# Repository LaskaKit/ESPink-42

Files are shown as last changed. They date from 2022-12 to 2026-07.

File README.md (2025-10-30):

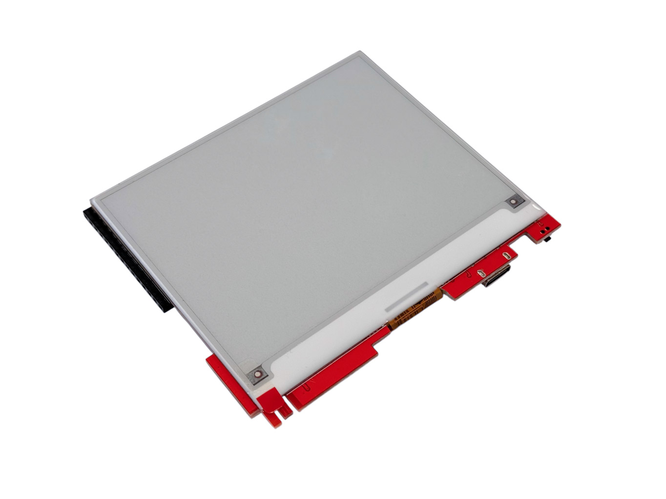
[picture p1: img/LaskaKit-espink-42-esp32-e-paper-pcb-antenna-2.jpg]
ESPink 4.2" top

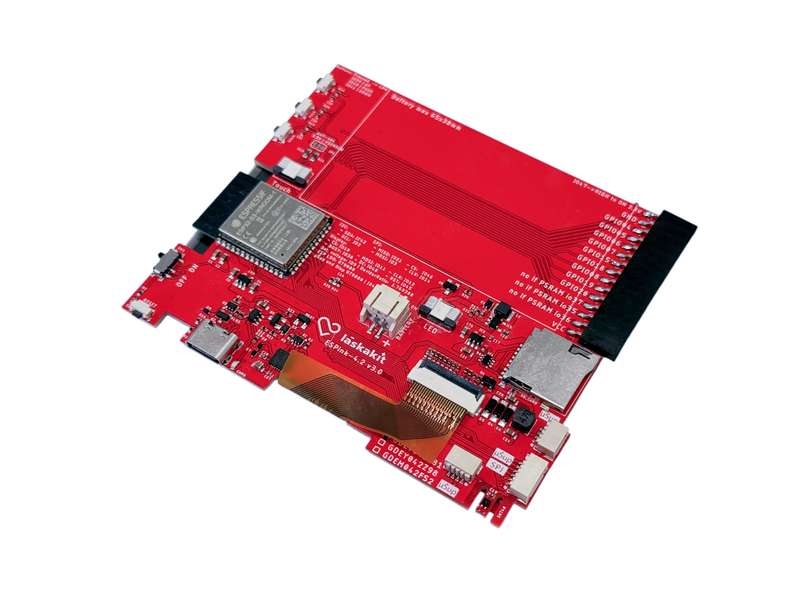
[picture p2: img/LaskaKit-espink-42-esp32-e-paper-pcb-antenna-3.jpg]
ESPink 4.2" bottom


# LaskaKit ESPink-4.2" — universal and ultra-low-power ESP32 board for 4.2" ePaper displays

[ePaper displays](https://www.laskakit.cz/e-ink/) are becoming incredibly popular — and for good reason.  
Their extremely low power consumption and wide viewing angle make them ideal for many battery-powered projects.  
But what’s the best way to drive such a display? That’s why we designed **ESPink** — a board with large memory, low power consumption, easy I²C sensor connection, and a huge maker community around ESP32.

---

## Main Features

The board naturally includes a connector for ePaper displays (sometimes referred to as *E-Ink*).  
While ePaper is very energy-efficient, it still draws a few microamps even when idle.  
To minimize this current, display power is controlled by a voltage regulator switched through **GPIO47**.  
The display power turns on when GPIO47 is set to HIGH.

The board can be powered by a **Li-Po battery**, which is charged via the **USB-C** connector.  
Battery voltage can be measured thanks to an integrated voltage divider connected to **GPIO9**.

Connecting sensors has never been easier or safer.  
No more broken sensors due to reversed polarity — with our **μŠup connector** (with a locking mechanism), you can plug sensors in quickly and securely.  
Compatible sensors include:  
- [LaskaKit SHT40 temperature and humidity sensor](https://www.laskakit.cz/laskakit-sht40-senzor-teploty-a-vlhkosti-vzduchu/)  
- [LaskaKit SCD41 CO₂, temperature, and humidity sensor](https://www.laskakit.cz/laskakit-scd41-senzor-co2--teploty-a-vlhkosti-vzduchu/)

The board also provides plenty of **GPIO pins** for your own extensions or modules.  
Power consumption in deep-sleep mode is extremely low — perfect for long-term battery projects.

---

## Important Notice

Recently shipped boards are equipped with **GoodDisplay displays**.  
The original **Waveshare** versions are no longer in production.  
At this time, there may be **incompatibility with ESPHome**, since support for new GoodDisplay panels is not yet fully implemented.  
If you plan to use ESPHome, please verify compatibility before purchase.

---

## Versions and Specifications

### ESPink-4.2" v3.0

| Display Type | Model | Colors | Refresh |
|---|---|---|---|
| Black & White | GDEQ042T81 | BW Grayscale | partial refresh |
| Black & White (touch + backlight) | GDEY042T81-FT02 | BW Touch | partial refresh |
| Red-Black-White | GDEY042Z98 | RBW | full refresh ~22 s |
| Yellow-Red-Black-White | GDEM042F52 | YRBW | full refresh ~20 s |

**ESP32 module:** ESP32-S3-N16R8 (16 MB Flash, 8 MB PSRAM)  
**Input voltage:** 3.7 – 5.5 V  
**Power consumption (deep-sleep):**
- Without touch: 16 µA  
- With touch: 4.5 mA for first 30 s, then 1.55 mA  
**Digital I/O pins:** 32  
**Analog inputs:** 16  
**Recommended battery:** GeB Li-Po 503759 – 1200 mAh  

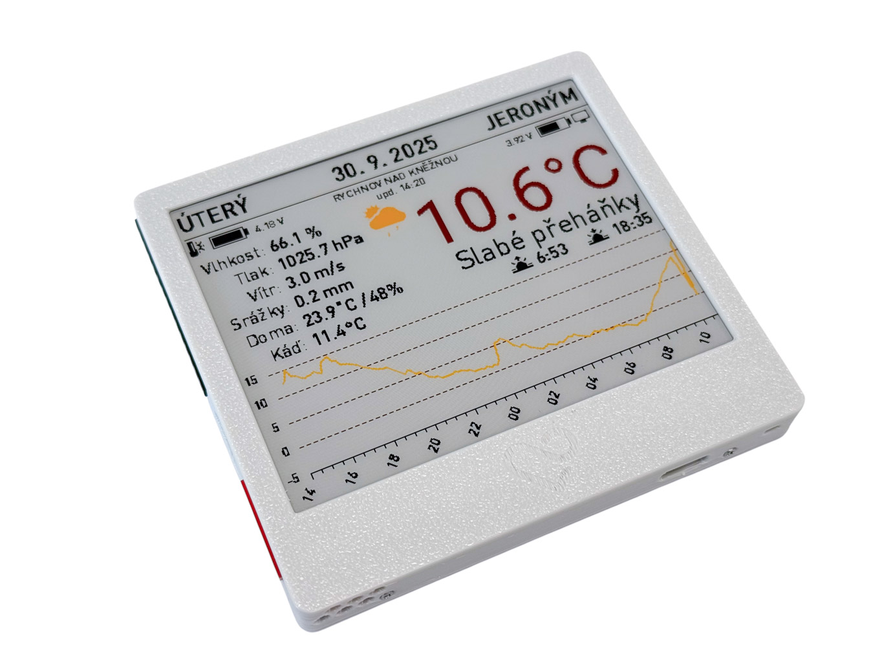
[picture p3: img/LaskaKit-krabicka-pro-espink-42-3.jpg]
ESPink 4.2" case


---

## Pinout (GxEPD2 standard)

| Function | Pin |
|---|-----|
| MOSI / SDI | 23 |
| CLK / SCK | 18 |
| SS / CS | 5 |
| DC | 17 |
| RST | 16 |
| BUSY | 4 |
| ePaper Power (HIGH = ON) | 47 |

---

## μŠup Connector Pinout

### SPI_uSUP
| Signal | Pin |
|---|-----|
| CS | 46 |
| MOSI | 3 |
| SCK | 14 |
| MISO | 21 |

### I2C_uSUP
| Signal | Pin |
|---|-----|
| SDA | 42 |
| SCL | 2 |

### SD Card
| Signal | Pin |
|---|-----|
| CS | 17 |
| MOSI | 11 |
| SCK | 12 |
| MISO | 13 |
| SD Insert | 16 |

### Buttons
| Function | Pins |
|---|---|
| Buttons | 39, 40, 41 |

---

📦 **Buy ESPink-4.2" in our e-shop:**  
➡️ [https://www.laskakit.cz/laskakit-espink-42-esp32-e-paper-pcb-antenna/](https://www.laskakit.cz/laskakit-espink-42-esp32-e-paper-pcb-antenna/)

💾 **Example codes and demos:**  
➡️ [https://github.com/LaskaKit/ESPink-42/tree/main/SW](https://github.com/LaskaKit/ESPink-42/tree/main/SW)

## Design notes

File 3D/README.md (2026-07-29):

#### Enclosure file moved to : https://github.com/LaskaKit/Live/tree/main/4.2

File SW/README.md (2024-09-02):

# How to make display work - Windows

1. Download [CH343SER.EXE](http://www.wch-ic.com/search?t=all&q=CH9102) and install it.

2. Connect display to your PC and turn it on with button on the side of the device (**single press to turn on, long press to turn off**).

3. Open Device Manager (Start → Control Panel → Hardware and Sound → Device Manager) and find COM port number.

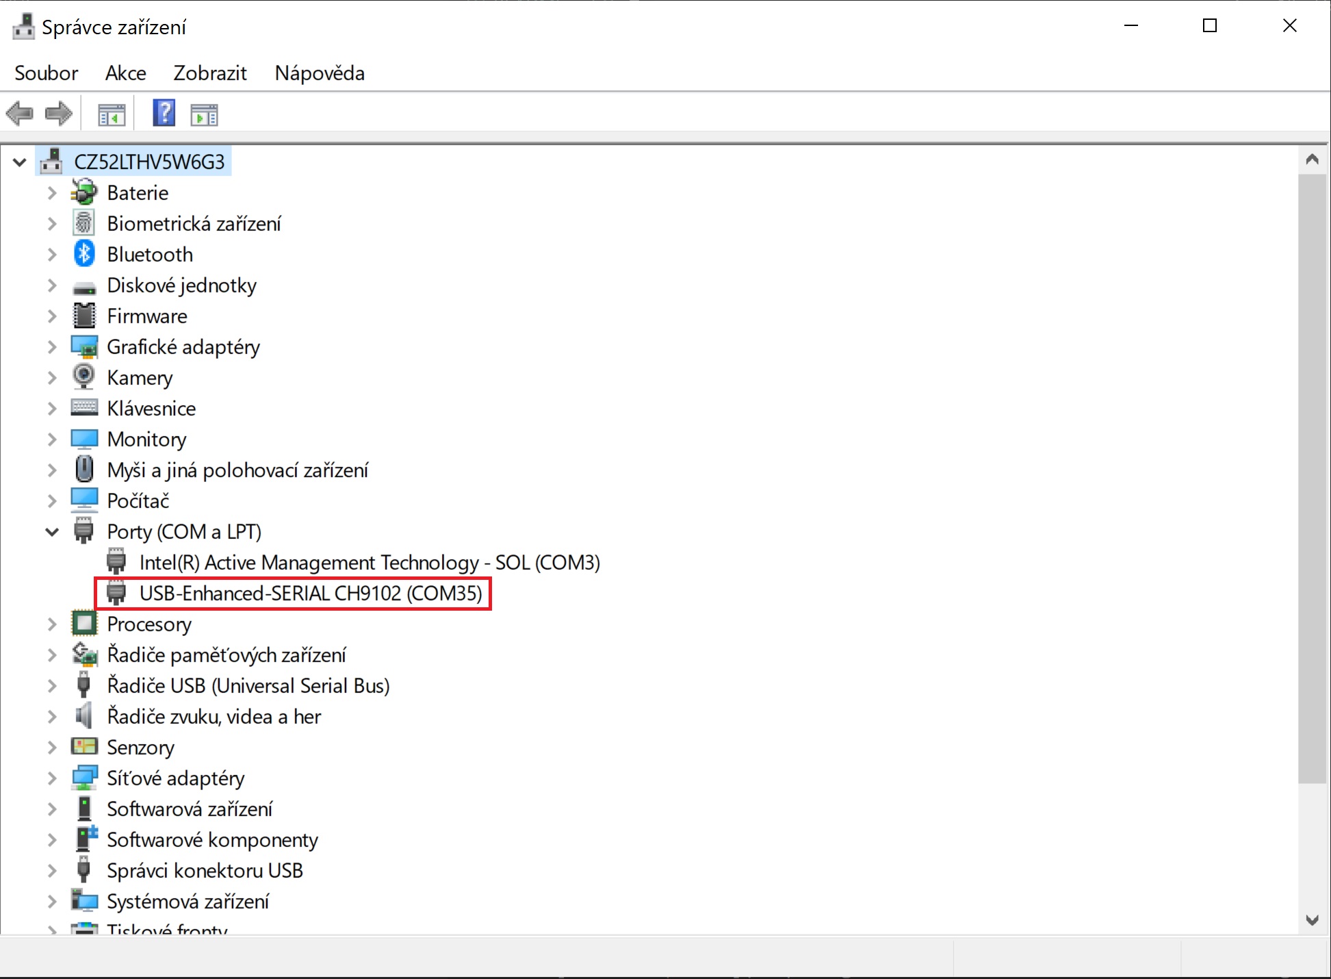
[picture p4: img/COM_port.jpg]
COM_port
    

## Arduino IDE
1. Download Github repository and look for project you want to try in [SW](../SW) folder.
2. Open example with Arduino IDE and set appropriate COM port and board type.
   
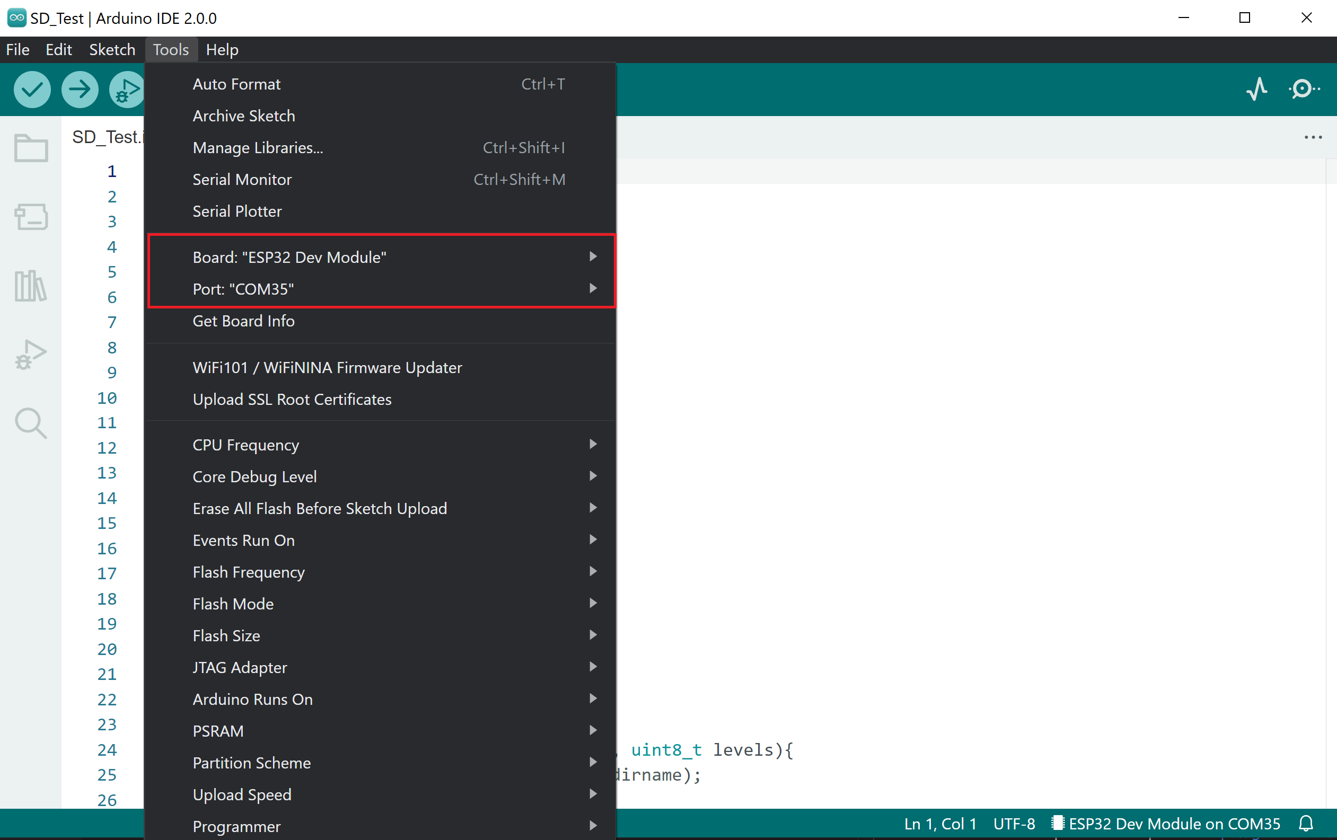
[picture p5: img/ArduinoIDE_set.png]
ArduinoIDE_set
    

3. Download necessary libraries.
4. Upload the code.
## Platform IO
1. Download Github repository and look for project you want to try in [SW](https://github.com/LaskaKit/ESPD-35/tree/main/SW) folder.
2. Open example with Platform IO. COM port should be set automaticaly.
3. Libraries will be downloaded automatically, because of lib_deps in platformio.ini.
4. Upload the code.

# How to make display work - Mac

1. Download [CH341SER_MAC.ZIP](https://www.wch-ic.com/search?t=all&q=CH9102) and unzip it
2. Run **CH34xVCPDriver.pkg** and follow the install instruction, reboot the Mac
3. Connect display to your Mac and turn it on with button on the side of the device

## Arduino IDE
1. Download Github repository and look for the project you want to try in [SW](../SW) folder.
2. Open example with Arduino IDE and set the appropriate serial port (/dev/cu.wuchsbserial) and board type.
   
ArduinoIDE_set
   
4. Download necessary libraries: [GxEPD2](https://github.com/ZinggJM/GxEPD2)
5. Upload the code.

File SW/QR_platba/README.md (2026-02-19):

# QR Platba na [ESPink4.2](https://www.laskakit.cz/laskakit-espink-42-esp32-e-paper-pcb-antenna/?variantId=13538) (ESP32 + e‑paper)

Projekt vytváří platební QR kód ve formátu Short Payment Descriptor (QR Platba, SPD 1.0) přímo na desce **[LaskaKit ESPink4.2](https://www.laskakit.cz/laskakit-espink-42-esp32-e-paper-pcb-antenna/?variantId=13538)** s ESP32 a 4,2" e‑paper displejem. Uživatel vyplní platební údaje přes webový formulář a výsledný QR kód se zobrazí na displeji, odkud jej zákazník naskenuje v mobilním bankovnictví.

Celý článek na našem blogu https://blog.laskakit.cz/epaper-jako-zobrazeni-qr-platby-pripravili-jsme-univerzalni-kod-zdarma-staci-pouzit/

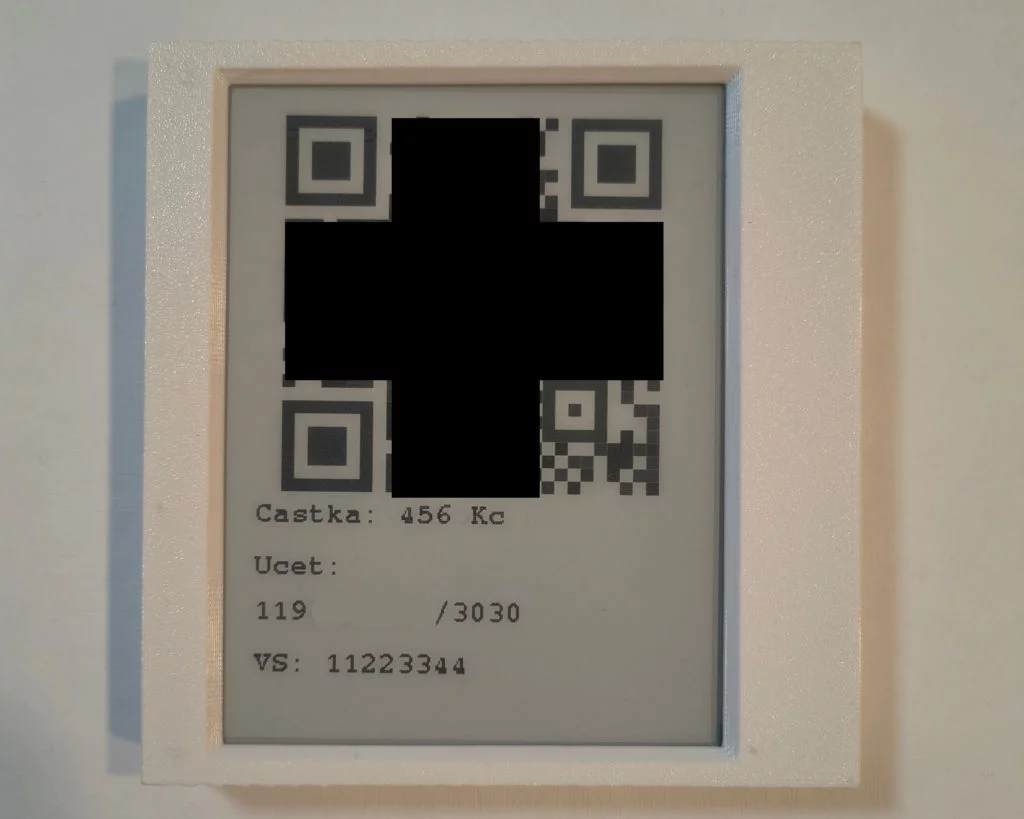
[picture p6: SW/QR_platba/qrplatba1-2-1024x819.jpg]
Obrazek


## Funkce

- Připojení k uložené Wi‑Fi nebo vytvoření vlastní Wi‑Fi AP **„Laskakit‑Platba_QR“** (heslo **„esp32qrpay“**) s jednoduchým webovým rozhraním.
- Webový formulář pro zadání částky (Kč), IBAN účtu, variabilního symbolu a data splatnosti a následné vygenerování QR platby.
- Generování platebního řetězce ve formátu SPD 1.0 a jeho zobrazení jako QR kódu na 4,2" e‑paper displeji.
- Uložení českého IBAN a Wi‑Fi přihlašovacích údajů do EEPROM a jejich opakované použití.
- Převod českého IBAN na domácí formát účtu (předčíslí‑číslo/kód banky) pro čitelný výpis na displeji.
- Administrační stránka `/admin` pro nastavení Wi‑Fi (SSID + heslo) a restart zařízení po uložení.

## Použitý hardware

Projekt je navržen pro:

- **LaskaKit ESPink4.2** – ESP32 modul s integrovaným 4,2" e‑paper displejem.
- ESP32 (WROOM) s Wi‑Fi.
- 4,2" e‑paper připojený přes SPI:
  - `PIN_SS` = 5  
  - `PIN_DC` = 17  
  - `PIN_RST` = 16  
  - `PIN_BUSY` = 4
- Řízení napájení e‑paper displeje na pinu `DISPLAY_POWER_PIN` (GPIO2).

Ostatní ESP32 piny jsou dle standardního zapojení desky ESPink4.2.

## Závislosti (knihovny)

Projekt je určen pro **Arduino IDE** (nebo kompatibilní build systém) s podporou ESP32.

Povinné knihovny:

- **WiFi.h** – Wi‑Fi připojení ESP32.
- **ESPAsyncWebServer** – asynchronní webový server (HTTP GET/POST, formuláře).
- **EEPROM.h** – ukládání IBAN a Wi‑Fi údajů.
- **GxEPD2_BW** – ovladač pro 4,2" e‑paper displej (černobílý režim).
- **qrcode_gen.h** (Ricmoo QRCode) – generování QR kódu z textového řetězce.
- **FreeMonoBold9pt7b** – font pro zobrazení textu na displeji.

Před kompilací ověř, že jsou knihovny nainstalované přes Library Manager nebo přidány jako Git submoduly.

## Kompilace

V Arduino IDE:

1. Nainstaluj podporu ESP32 (Boards Manager).
2. Otevři projektový `.ino` nebo `.cpp` soubor.
3. V **Tools → Board** vyber **ESP32 Dev Module**.
4. Nastav správný port a klikni na **Upload**.

## Jak to funguje

1. ESP32 po startu načte z EEPROM uložené Wi‑Fi přihlašovací údaje.
2. Pokusí se připojit k Wi‑Fi (režim STA) po dobu cca 20 s.
3. Pokud se nepřipojí, vytvoří vlastní AP **„Laskakit‑Platba_QR“** s heslem **„esp32qrpay“**.
4. Na e‑paper displeji zobrazí stav Wi‑Fi (připojeno/AP režim), SSID a IP adresu.
5. Na kořenové URL `/` běží stránka s formulářem:
   - Částka v Kč.
   - IBAN (český, formát CZ…).
   - Variabilní symbol (volitelné).
   - Datum splatnosti (volitelné).
6. Po odeslání na `/qr` proběhne:
   - Očištění IBAN od mezer a nealfanumerických znaků.
   - Kontrola, že IBAN začíná `CZ` a má délku 24 znaků.
   - Kontrola částky > 0.
   - Validace VS (max. 10 číslic).
   - Uložení IBAN do EEPROM (pokud se změnil).
   - Vytvoření SPD řetězce a vygenerování QR kódu.
   - Vykreslení QR kódu a textových údajů (částka, účet, VS) na e‑paper displej.
7. Admin stránka `/admin` umožní změnu Wi‑Fi SSID/hesla a restart zařízení.

## End‑pointy

- `GET /` – hlavní stránka pro zadání platebních údajů a vytvoření QR kódu.
- `GET /qr` – zpracování formuláře, validace vstupů, generování QR platby a vykreslení na e‑paper.
- `GET /admin` – formulář pro nastavení Wi‑Fi (SSID a heslo).
- `POST /wifi_save` – uložení Wi‑Fi údajů do EEPROM a restart ESP32.

## Bezpečnost a omezení

- Ukládání údajů do EEPROM není šifrované, projekt je tedy vhodný pro jednoduché pokladní/klubové použití, ne pro kritické scénáře.
- Validace je primárně uzpůsobena českému IBAN (`CZ` + 24 znaků).
- Okamžité platby jsou indikované parametrem `PT:IP` pouze na úrovni SPD řetězce – skutečné provedení závisí na bance.

## Možné vylepšení

- Přidání zprávy pro příjemce a dalších volitelných SPD parametrů.
- Volitelné předvyplnění částky a VS (např. přes query parametry v URL).
- Podpora více účtů nebo profilů.
- Jednoduchá ochrana admin rozhraní (heslo, PIN).

## Hardware

Celý článek na našem blogu https://blog.laskakit.cz/epaper-jako-zobrazeni-qr-platby-pripravili-jsme-univerzalni-kod-zdarma-staci-pouzit/

ESPink-42 můžete zakoupit na https://www.laskakit.cz/laskakit-espink-42-esp32-e-paper-pcb-antenna/?variantId=13538

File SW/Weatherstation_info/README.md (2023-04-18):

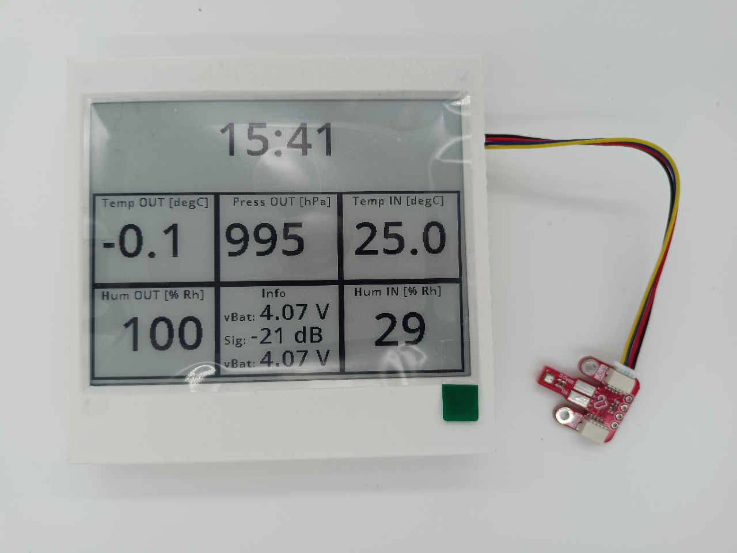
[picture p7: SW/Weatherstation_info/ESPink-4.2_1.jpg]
</br>
</br>
Example code shows values from weatherstation from TMEP.cz (temperature, humidity, pressure, battery voltage) 
and BME280 (temperature/humidity), battery voltage on eInk/ePaper display</br>
</br>
Compile as ESP32 dev module</br>
ESPink - ESP32 board for ePaper: https://www.laskakit.cz/laskakit-espink-esp32-e-paper-pcb-antenna/</br>
BME280 (https://www.laskakit.cz/arduino-senzor-tlaku--teploty-a-vlhkosti-bme280/) is connected through uSup connector </br>
</br>
ESPink pinout:</br>
MOSI/SDI 23</br>
CLK/SCK 18</br>
SS 5 //CS</br>
DC 17 </br>
RST 16  </br>
BUSY 4 </br>
ePaperPowerPin  2</br>
</br>
I2C pinout:</br>
SDA 21</br>
SCL 22</br>
</br>
Battery input:</br>
vBatPin 34</br>
</br>
Need to change based on your settings:</br>
WiFi (SSID and Password)</br>
TMEP server (jsonurl)</br>
</br>
Libraries:</br>
Analog read with calibration data: https://github.com/madhephaestus/ESP32AnalogRead/ </br>
EPD library: https://github.com/ZinggJM/GxEPD2</br>
ArduinoJson: https://arduinojson.org/</br>
Font: https://oleddisplay.squix.ch/ </br>
BME280: https://github.com/adafruit/Adafruit_BME280_Library</br>
https://github.com/adafruit/Adafruit_Sensor</br>
</br>
made by laskakit (c) 2023</br>
</br>
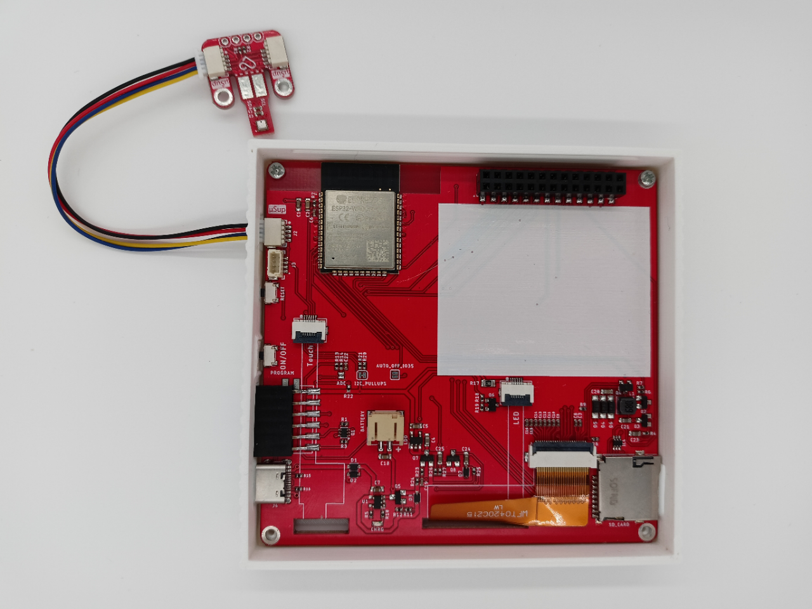
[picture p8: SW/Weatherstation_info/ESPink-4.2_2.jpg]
</br>

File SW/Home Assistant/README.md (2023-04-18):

# How to make display work

1. Add text from configuration.yaml to your configuration.yaml in Home Assistant (you do not have to change anything for testing, otherwise edit it to your needs).
   
2. Place fonts folder into esphome/config.

3. Add display to esphome and Home Assistant.
   
4. Copy text from espink.yaml to your device config yaml and edit necessary parameters. **Name of the device has to match your added device name.**

5. Upload code to your device. From now on, you are able to upload code wirelessly, just locally, because device is most of the time in sleep mode.

# What does it do?
It prints data from [TMEP](https://tmep.cz/) on the display after getting them from Home Assistant and goes to sleep.

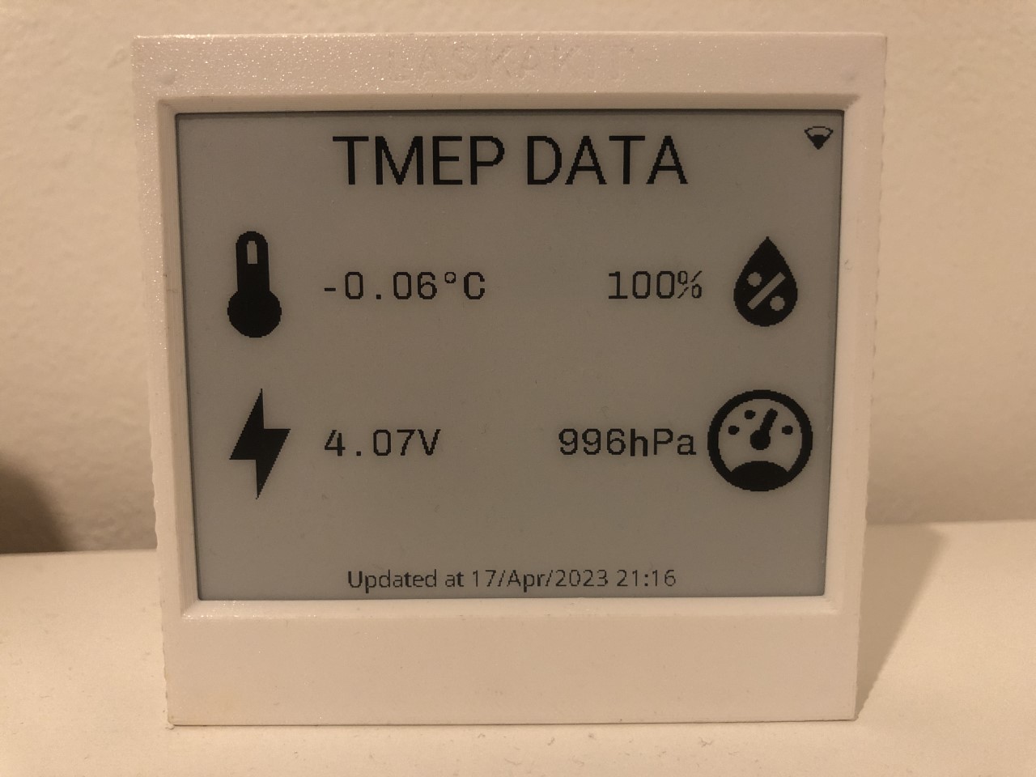
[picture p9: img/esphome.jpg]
esphome


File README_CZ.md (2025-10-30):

ESPink 4.2" top
ESPink 4.2" bottom

# LaskaKit ESPink-4.2" — univerzální a velmi úsporná deska s ESP32 pro 4.2" ePaper

[ePaper displeje](https://www.laskakit.cz/e-ink/) nabírají neuvěřitelné popularity a není divu.  
Především velmi nízký odběr a široký pozorovací úhel dělá ePaper tak populárním.  
Ale čím tento displej řídit? Proto jsme navrhli **ESPink** — desku s velkou pamětí, nízkým odběrem, snadným připojením I2C čidel a velkou komunitou bastlířů okolo ESP32.

---

## Hlavní vlastnosti

Na desce samozřejmě najdete konektor pro ePaper displeje (někdy označovaný jako *E-Ink*).  
Displej sám o sobě je velmi úsporný, ale i mimo fázi přepisu odebírá několik mikroampér.  
Abychom tento odběr minimalizovali, je napájení displeje řízené stabilizátorem spínaným přes **GPIO47**.  
Napájení ePaperu se tedy zapne, když je GPIO47 nastaven do HIGH.

Deska může být napájena z **LiPol akumulátoru**, který se nabíjí přes **USB-C** konektor.  
Napětí akumulátoru lze měřit díky integrovanému děliči připojenému na **GPIO9**.

Připojení čidel nebylo nikdy snadnější ani bezpečnější.  
Žádná nefunkční čidla kvůli přepólování — díky našemu **μŠup konektoru**, který obsahuje zámek, čidlo jednoduše a bezpečně připojíte.  
Mezi taková čidla patří například:  
- [LaskaKit SHT40 senzor teploty a vlhkosti vzduchu](https://www.laskakit.cz/laskakit-sht40-senzor-teploty-a-vlhkosti-vzduchu/)  
- [LaskaKit SCD41 senzor CO₂, teploty a vlhkosti vzduchu](https://www.laskakit.cz/laskakit-scd41-senzor-co2--teploty-a-vlhkosti-vzduchu/)

Na desce je také dostatek **GPIO pinů** pro rozšiřující moduly nebo vlastní projekty.  
Odběr v hlubokém spánku (deep-sleep) je velmi nízký — ideální pro bateriové projekty.

---

## Důležité upozornění

Nově prodávané desky využívají **displeje od výrobce GoodDisplay**.  
Původní displeje od **Waveshare** se již nevyrábějí.  
V současné době může být **nekompatibilita s ESPHome**, protože zatím není implementována podpora pro nové displeje GoodDisplay.  
Pokud používáte ESPHome, doporučujeme tuto informaci ověřit před nákupem.

---

## Verze a parametry

### ESPink-4.2" v3.0

| Typ displeje | Model | Barvy | Obnova |
|---|---|---|---|
| Černo-Bílý | GDEQ042T81 | BW Grayscale | částečný refresh |
| Černo-Bílý (dotyk + podsvit) | GDEY042T81-FT02 | BW Touch | částečný refresh |
| Červeno-Černo-Bílý | GDEY042Z98 | RBW | full refresh ~22 s |
| Žluto-Červeno-Černo-Bílý | GDEM042F52 | YRBW | full refresh ~20 s |

**ESP32 modul:** ESP32-S3-N16R8 (16 MB Flash, 8 MB PSRAM)  
**Napájení:** 3.7 – 5.5 V  
**Odběr (deep-sleep):**
- Bez dotyku: 16 µA  
- S dotykem: 4.5 mA prvních 30 s, poté 1.55 mA  
**Digitální I/O piny:** 32  
**Analogové vstupy:** 16  
**Vhodná baterie:** GeB LiPol 503759 – 1200 mAh  

ESPink 4.2" bottom

---

## Pinout (GxEPD2 standard)

| Funkce | Pin |
|---|-----|
| MOSI / SDI | 23 |
| CLK / SCK | 18 |
| SS / CS | 5 |
| DC | 17 |
| RST | 16 |
| BUSY | 4 |
| Napájení ePaperu (HIGH = ON) | 47 |

---

## Pinout konektorů μŠup

### SPI_uSUP
| Signál | Pin |
|---|-----|
| CS | 46 |
| MOSI | 3 |
| SCK | 14 |
| MISO | 21 |

### I2C_uSUP
| Signál | Pin |
|---|-----|
| SDA | 42 |
| SCL | 2 |

### SD karta
| Signál | Pin |
|---|-----|
| CS | 17 |
| MOSI | 11 |
| SCK | 12 |
| MISO | 13 |
| SD Insert | 16 |

### Tlačítka
| Funkce | Piny |
|---|---|
| Buttons | 39, 40, 41 |

---

📦 **ESPink-4.2" na e-shopu:**  
➡️ [https://www.laskakit.cz/laskakit-espink-42-esp32-e-paper-pcb-antenna/](https://www.laskakit.cz/laskakit-espink-42-esp32-e-paper-pcb-antenna/)

💾 **Vzorové kódy a ukázky:**  
➡️ [https://github.com/LaskaKit/ESPink-42/tree/main/SW](https://github.com/LaskaKit/ESPink-42/tree/main/SW)

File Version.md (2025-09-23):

### Version 3.1
- More place for flex cable
- Added one more capacitor 47uF for ESP
#### Version 3.0
- Whole new board on ESP32-S3
- pull down added to backlight pin
#### Version 3.0
- Whole new board on ESP32-S3
#### Version 2.3
- ESPD power delivery changed | Napájení ESPD změněno
- Battery voltage mesurement changed, used MAX17048 instead od ADC (First 5 minutes deep sleep current is 34 µA (before MAX17048 go to hibernate), after 5 min 14 µA) | Měření napětí baterie se změnilo, místo ADC se používá MAX17048 (prvních 5 minut deep sleep proud je 34 µA (než MAX17048 přejde do režimu spánku), po 5 minutách 14 µA)
- Resistor R9 changed to 0.47 Ohm | Rezistor R9 změněn na 0,47 Ohm
- µSup SPI connector added | Přidán konektor µSup SPI
#### Version 2.2
- Added switched stabilizer for µShup on pin 02 | Pridán spinaný stabilizator pro µŠup na pinu 02
- Changing the scheme connection for the touch panel on the new display | Změna zapojení konektoru pro touch panel na nové displeje
- Changing the scheme connection for the backlight on the new display | Změna zapojení konektoru pro podsvícení na nové displeje
- Added a 3.3V-21V converter for powering the backlight |Přidán měnič 3,3V-21V pro napájení podsvícení
- Changing the way to turn on the backlight |Změna způsobu zapínání podsvícení
#### Version 2.1
- Switch to classic switch. |změna vypinani na klasický vypinač
#### Version 2.0
- Add USB - TTL adapter | Přidan adaptér USB - TTL
- Replaced microSD card holder | Vyměněn držák microSD karty
#### Version 1.2
- Initial | Počáteční

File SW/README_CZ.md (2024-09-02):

# Jak pracovat s displejem

1. Stáhnout [CH343SER.EXE](http://www.wch-ic.com/search?t=all&q=CH9102) a nainstalovat. Návod i na našem [blogu](https://blog.laskakit.cz/instalace-ovladace-prevodniku-usb-na-uart-ch340/).

2. Zapojit displej do PC a zapnout tlačítkem na boku (**stisk pro zapnutí, dlouhý stisk pro vypnutí**).

3. Start – Systém – Správce zařízení (může být potřeba oprávnění správce) najít položku Porty (COM a LPT).

    COM_port

## Arduino IDE
1. Stáhnout Github repository a otevřít příklad, který chcete zkusit ze složky [SW](../SW).
2. Otevřít příklad pomocí Arduino IDE a nastavit správný COM port a typ desky.
   
    ArduinoIDE_set

3. Stáhnout nezbytné knihovny: [GxEPD2](https://github.com/ZinggJM/GxEPD2)
4. Nahrát kód.
## Platform IO
1. Stáhnout Github repository a otevřít příklad, který chcete zkusit ze složky [SW](../SW).
2. Otevřít příklad pomocí Arduino IDE a nastavit správný COM port a typ desky. COM port by měl být nastaven automaticky.
3. Knihovny se stáhnou automaticky díky lib_deps v souboru platformio.ini.
4. Nahrát kód.

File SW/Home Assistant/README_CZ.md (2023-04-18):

# Jak uvést do chodu displej

1. Přidat text z configuration.yaml do configuration.yaml v Home Assistant (není potřeba nic měnit na vyzkoušení, jinak je nezbytné upravit parametry podle sebe).
   
2. Vložit složku fonts do esphome/config.

3. Přidat displej do esphome a Home Assistant.
   
4. Zkopírovat text z espink.yaml do yaml konfigurace zařízení  a upravit nezbytné parametry. **Jméno zařízení se musí shodovat se jménem předem nakonfigurovaného zařízení.**

5. Nahrát program do zařízení. Odteď už nebude možné nahrát kód do zařízení bezdrátově, pouze lokálně, protože zařízení tráví většinu času v režimu spánku.

# Co kód dělá?
Zobrazí data z [TMEP](https://tmep.cz/) na displej po jejich stažení z Home Assistant a uspí se.

esphome

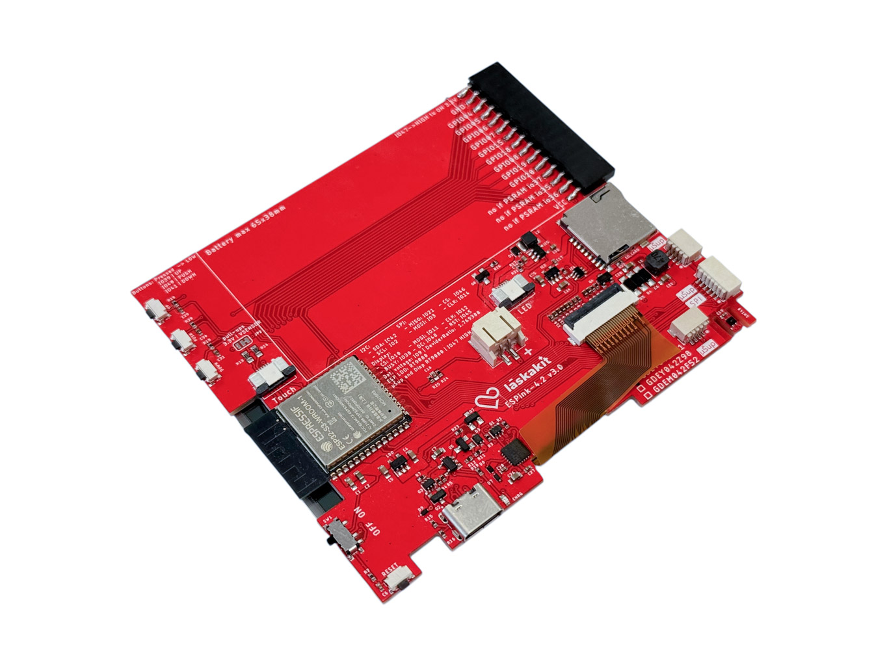
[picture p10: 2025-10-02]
img/LaskaKit-espink-42-esp32-e-paper-pcb-antenna-1.jpg

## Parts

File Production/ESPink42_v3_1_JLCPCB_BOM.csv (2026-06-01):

Comment | Designator | Footprint | LCSC Part #
JST-PH-2_SMD/90SMD | BATTERY | S2B-PH-SM4 | C47647
100nF | C1 | C0603
1uF/25V | C9 C10 C11 C16 | C0402
4.7uF/25V | C3 C8 C12 C13 C14 C15 | C0402
47uF | C2 C32 | C0603 | C178330
4.7uF/25V | C20 | C0603
10uF/25V | C21 | C0603
10uF/16V | C4 C24 C25 | C0603
10uF/16V | C5 | C0603 | C108344
100nF | C6 C17 C18 C19 | C0402
10uF | C7 | C0603
RED | CHRG | CHIP-LED0603 | C2286
MBR0530 | D4 D5 D6 | SOD123-F
47uH/1A | L1 | SMNR4020
RT9080-33GJ5 | IC2 LDO | SOT94P280X100-5N
MMDT3904 | Q1 | SC70-6 | C268586
5.8A/30V/35mΩ | Q4 | SOT23-3 | C20917
10k | R1 R2 R3 R6 R11 R18 R19 R20 R22 R26 | R0402
3.3k | R10 | R0402
1M | R8 R24 | R0402
2.2R | R9 | R0402
TP4054 | U1 | SOT-23-5 | C32574
USB-C_GT-USB-7010B | J4 | G-SWITCH_GT-USB-7010B | C2837092
5.1k | R15 R16 | R0402
JST-SH-4_RA | J2 | 1X04_1MM_RA
1k | R5 | R0402
MICRO_SD | SD_CARD | MICRO_SD | C91145
SMF05C | IC4 | SOT65P210X110-6N | C558425
AO3401 | Q5 Q7 | SOT23
100k | R12 R23 R27 | R0402
BAT60B | D3 | SOD323-R
JST-SH-4_VERT | J3 | 1X04_1MM_RA
22uF | C26 | C0603
100n | C27 C28 | C0402
CH9102F | IC3 | QFN24-4X4
SSSS811101 | SW1 | SSSS811101
ESP32-S3-WROOM-1-N16R8 | IC1 | ESP32S3WROOM1N16R8
USUP_SPI_CONNECTOR | J5 | 1X06_1MM_RA
4.7k | R13 R14 | R0603
SHT40 | SHT40 | SHT40
1TS003B-1600-3500A | DOWN PUSH RESET UP | 1TS003B16003500A
1x15 | JP1 | 1X15-F-SMD | C5142248
LESD5D5.0CT1G | D7 D8 D9 | LESD5D50CT1G
1uF | C29 C30 C31 | C0402
MMDT5401 | Q3 | SC70-6 | C54540
DMG2305UX | Q2 | MICRO3 | C144153
47k | R4 R7 | R0402
1.3M | R25 | R0402
AP3012 | IC5 | SOT95P280X135-5N | C460356
22uF | C22 | C0402
22uF/25V | C23 | C0603
10uH | L2 | L1210 | C86069
1N5819WS | D1 | SOD323-R
91k | R17 | R0402
5.76k | R21 | R0402
AO3400 | Q8 | SOT23
AFC24-S24FIA-00 | DISPLAY | AFC24-S24FIA-00 | C262683
AFC07-S06ECA-00 | LED TOUCH | AFC07-S06ECA-00 | C262579

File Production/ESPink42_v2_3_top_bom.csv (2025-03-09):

Comment | Designator | Footprint | LCSC Part #
0.47R | R9 | R0402
1.3M | R7 | R0402
1M | R6 | R0402
1N5819WS | D7 | SOD323-R
1TS003B-1600-3500A | RESET | 1TS003B16003500A
1k65 | R5 | R0402
1uF | C3 | C0402
1uF | C7 | C0603
1uF | C8 C9 C10 C11 C12 C13 C14 C15 C16 | C0402
4 7uF | C5 | C0603 | C108344
4.7k | R20 R21 | R0402
4.7uF | C20 | C0603
5.1k | R15 R16 | R0402
5.76k | R25 | R0402
10k | R1 R2 R3 R8 R11 R17 R22 | R0402
10uF | C21 | C0603
10uH | L2 | L1210 | C86069
22uF | C4 | C0603
22uF | C18 C19 | C0402
22uF | C23 C24 C25 C26 C29 | C0603
47uF | C2 | C0603 | C178330
68uH | L1 | SMNR4020 | C135265
91k | R24 | R0402
100 | R14 | R0402
100k | R12 R13 R19 R23 | R0402
100n | C22 C27 C28 | C0402
100nF | C1 | C0603
100nF | C6 C17 | C0402
330 | R10 | R0402
AO3400 | Q4 Q8 | SOT23
AO3401 | Q5 Q7 | SOT23
AP2191WG-7 | IC5 IC7 | SOT25 | C141321
AP3012 | IC1 | SOT95P280X135-5N | C460356
BAT60B | D1 D2 D3 | SOD323-R | C514095
BLM18KG221SN1D | L3 | R0603 | C88980
BSS806NEH6327 | Q3 | SOT23 | C91714
CH9102F | IC3 | QFN24-4X4
ESP32-WROOM | ESP32 | ESP32WROOM32D | C529595
FEMALE_LOW_2X13 | J1 | FEMALE_LOW_2X13
HT7833 | LDO | SOT23-5 | C164106
IRLML2244TRPBF | Q2 | SOT23 | C169763
JST-PH-2/90SMD | BATTERY | S2B-PH-SM4 | C47647
JST-SH-4_RA | J2 | 1X04_1MM_RA | C145956
JST-SH-4_VERT | J3 | 1X04_1MM_RA_VERT | C371588
MBR0530 | D4 D5 D6 | SOD123-F
ME6211C33M5G | IC2 | SOT23-5
MICRO_SD | SD_CARD | MICRO_SD | C91145
MMDT3904 | Q1 | SC70-6 | C268586
RED | CHRG | CHIP-LED0603 | C2286
SMD0805-050 | F1 F2 | 0805L | C66452
SMF05C | IC4 | SOT65P210X110-6N | C558425
SSSS811101 | SW1 | SSSS811101
TP4054 | U1 | SOT-23-5 | C32574
USB-C_2-16PIN | J4 | USBC_USB-C-16P-5 | C2837092
USUP_SPI_CONNECTOR_VERT | J5 | 1X06_1MM_RA_VERT | C145963
AFC24-S24FIC-00 | DISPLAY | AFC24-S24FIC-00 | C262292
AFC07-S06ECA-00 | LED TOUCH | AFC07-S06ECA-00 | C262579

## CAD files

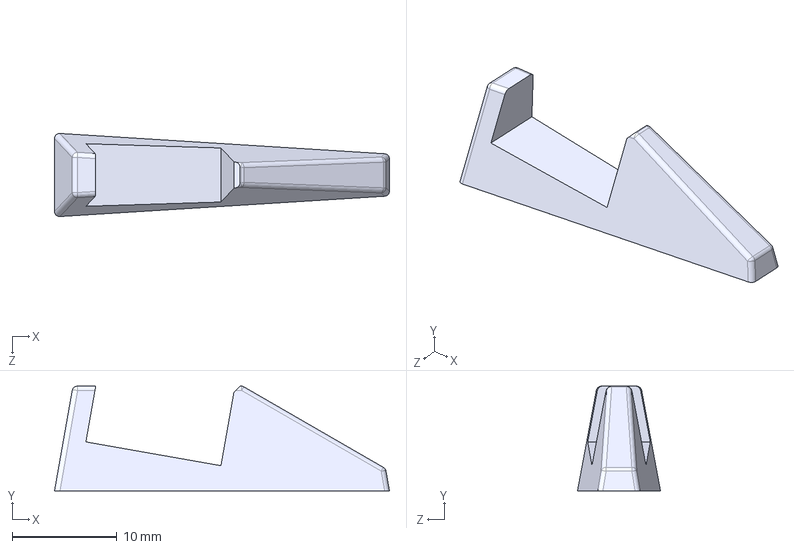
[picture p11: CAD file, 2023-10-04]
3D/Nozka_1_V2.STEP
32.0 x 10.0 x 7.94 mm

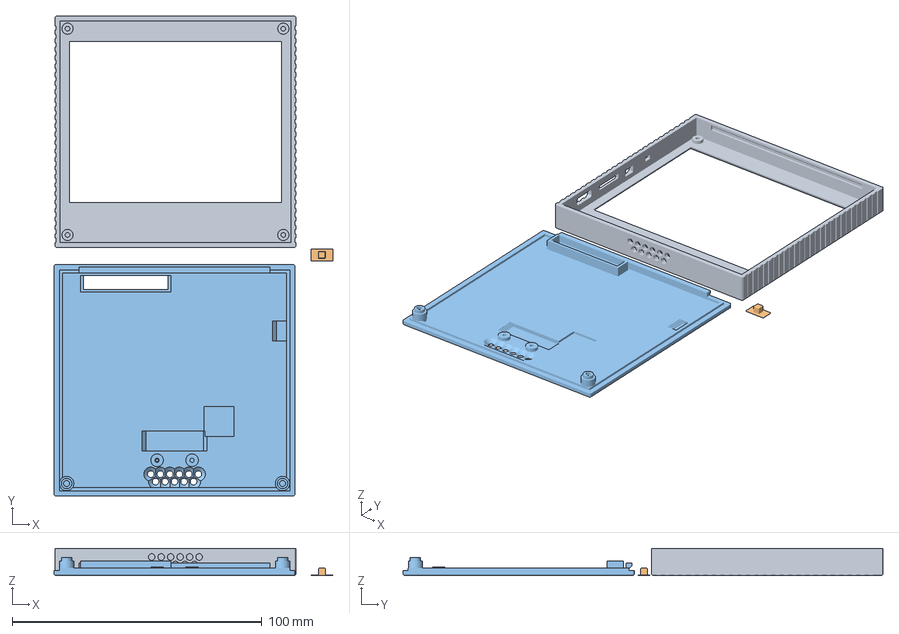
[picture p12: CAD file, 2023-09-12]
3D/ESPink-42_case.3mf
111.6 x 192.1 x 11.0 mm
Top_cover_v2 v46.stl
button v15.stl
Bottom_cover v67.stl

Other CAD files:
3D/ESPink42_v3_1.f3d
3D/Nozka_1_V2.STL
3D/old/ESPink42_v3_1.f3d
3D/old/Nozka_1_V2.STL

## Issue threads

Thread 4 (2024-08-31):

Compatibility with arduino-esp32: 3.x

PexMor, 2024-08-31:
https://github.com/LaskaKit/ESPink-42/blob/da1134c9fca5b908fcb62d94b190ed9c36872ec6/SW/Simple/Touch_and_light_example/Touch_and_light_example.ino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

TL-DR: replace with `ledcAttach(DISPLAY_LED, 1000, 8);`

The lines above has new form on ardiuno-esp32 v3.x

The two lines updated with:

```c
// configure backlight LED PWM functionalitites
// ledcSetup(1, 1000, 8);          // ledChannel, freq, resolution
// ledcAttachPin(DISPLAY_LED, 1);  // ledPin, ledChannel
// was 2.x:
// ledcSetup(X_PWM_CHANNEL, X_PWM_FREQ, PWM_RESOLUTION);
// ledcAttachPin(X_PWM_OUT, X_PWM_CHANNEL);
// ledcSetup(channel, freq, resolution);
// ledcAttachPin(used_pin, channel);
// new 3.x:
// bool ledcAttach(uint8_t pin, uint32_t freq, uint8_t resolution);

ledcAttach(DISPLAY_LED, 1000, 8);
```

Konstantin-G, 2024-09-02:
Updated, thanks

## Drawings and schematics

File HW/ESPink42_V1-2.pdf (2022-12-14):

A

A

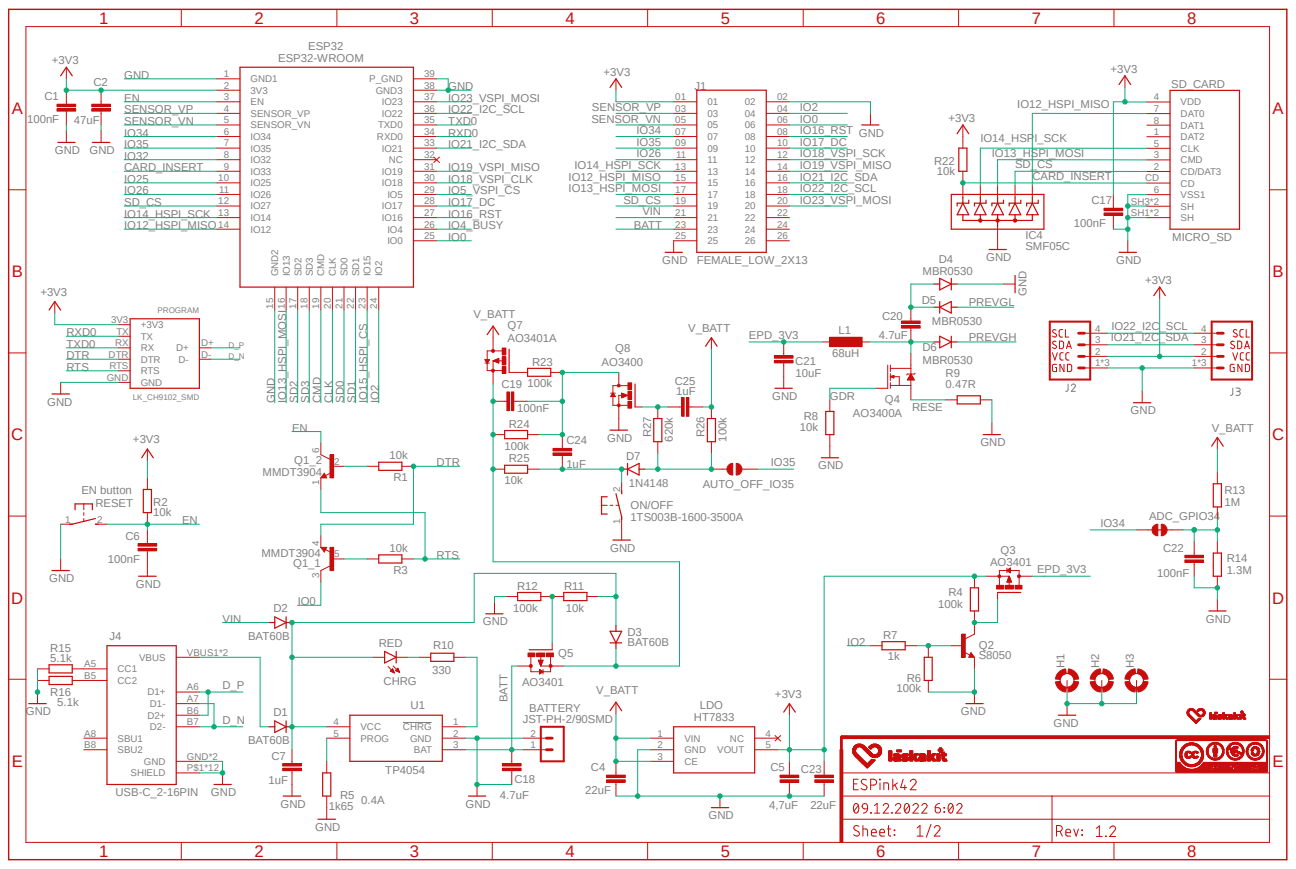
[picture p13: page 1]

# 1uF GND

10 10 | 11 11 | 12 12 | 13 13 | 14 14 | 15 15 | 16 16 | 17 17 | 18 18 | 19 19 | 20 20 | 21 21 | 22 22 | 23 23 | 24 24

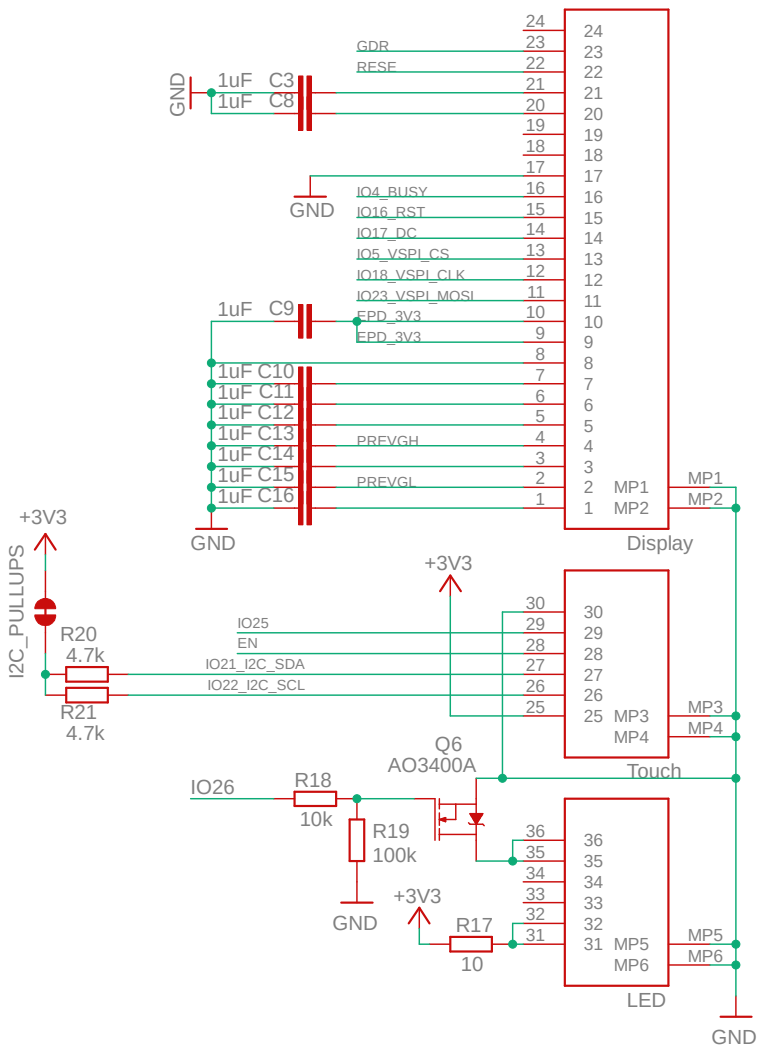
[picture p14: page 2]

1uF C10 | 7
1uF C11 | 6
1uF C12 | 5
1uF C13 | 4 PREVGH
1uF C14 | 3
1uF C15 | PREVGL 2
C16 | 1

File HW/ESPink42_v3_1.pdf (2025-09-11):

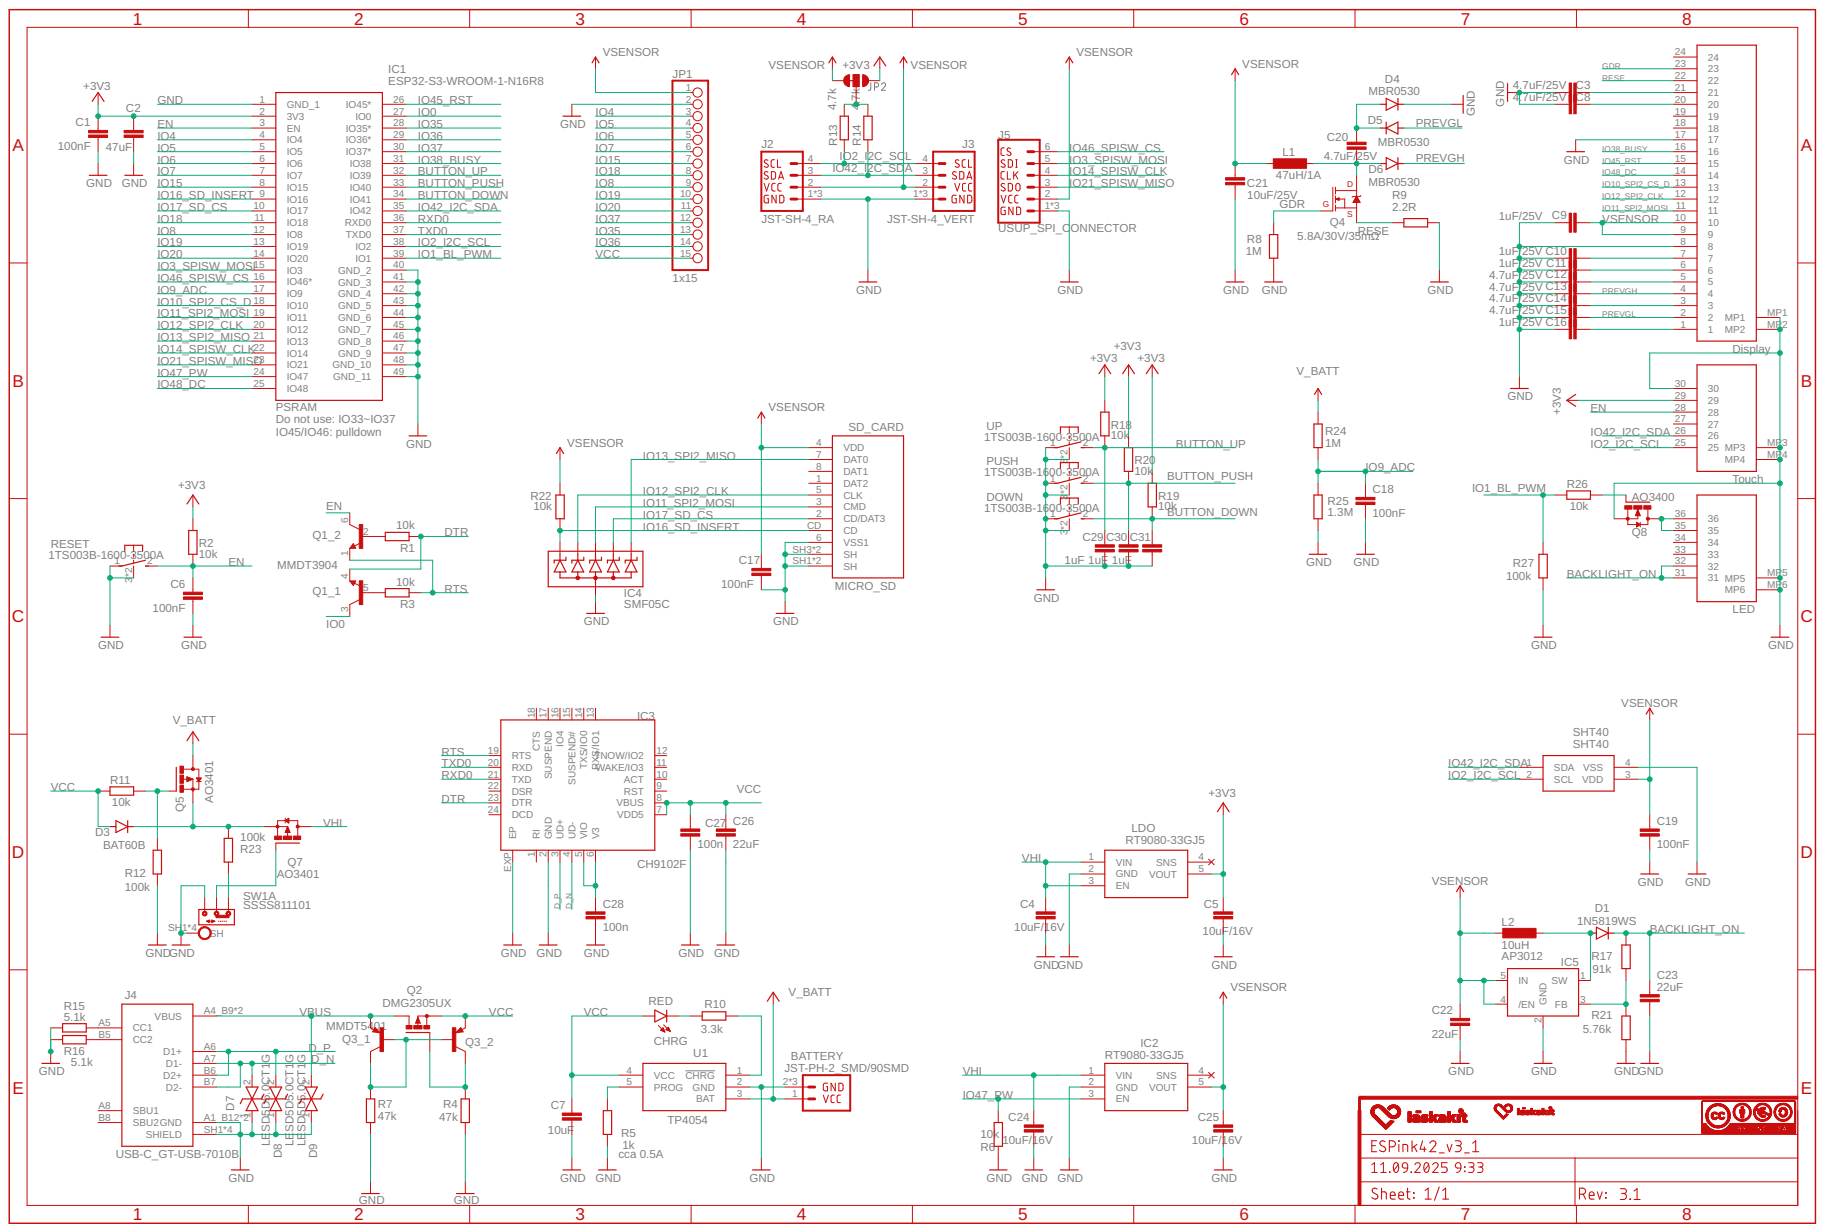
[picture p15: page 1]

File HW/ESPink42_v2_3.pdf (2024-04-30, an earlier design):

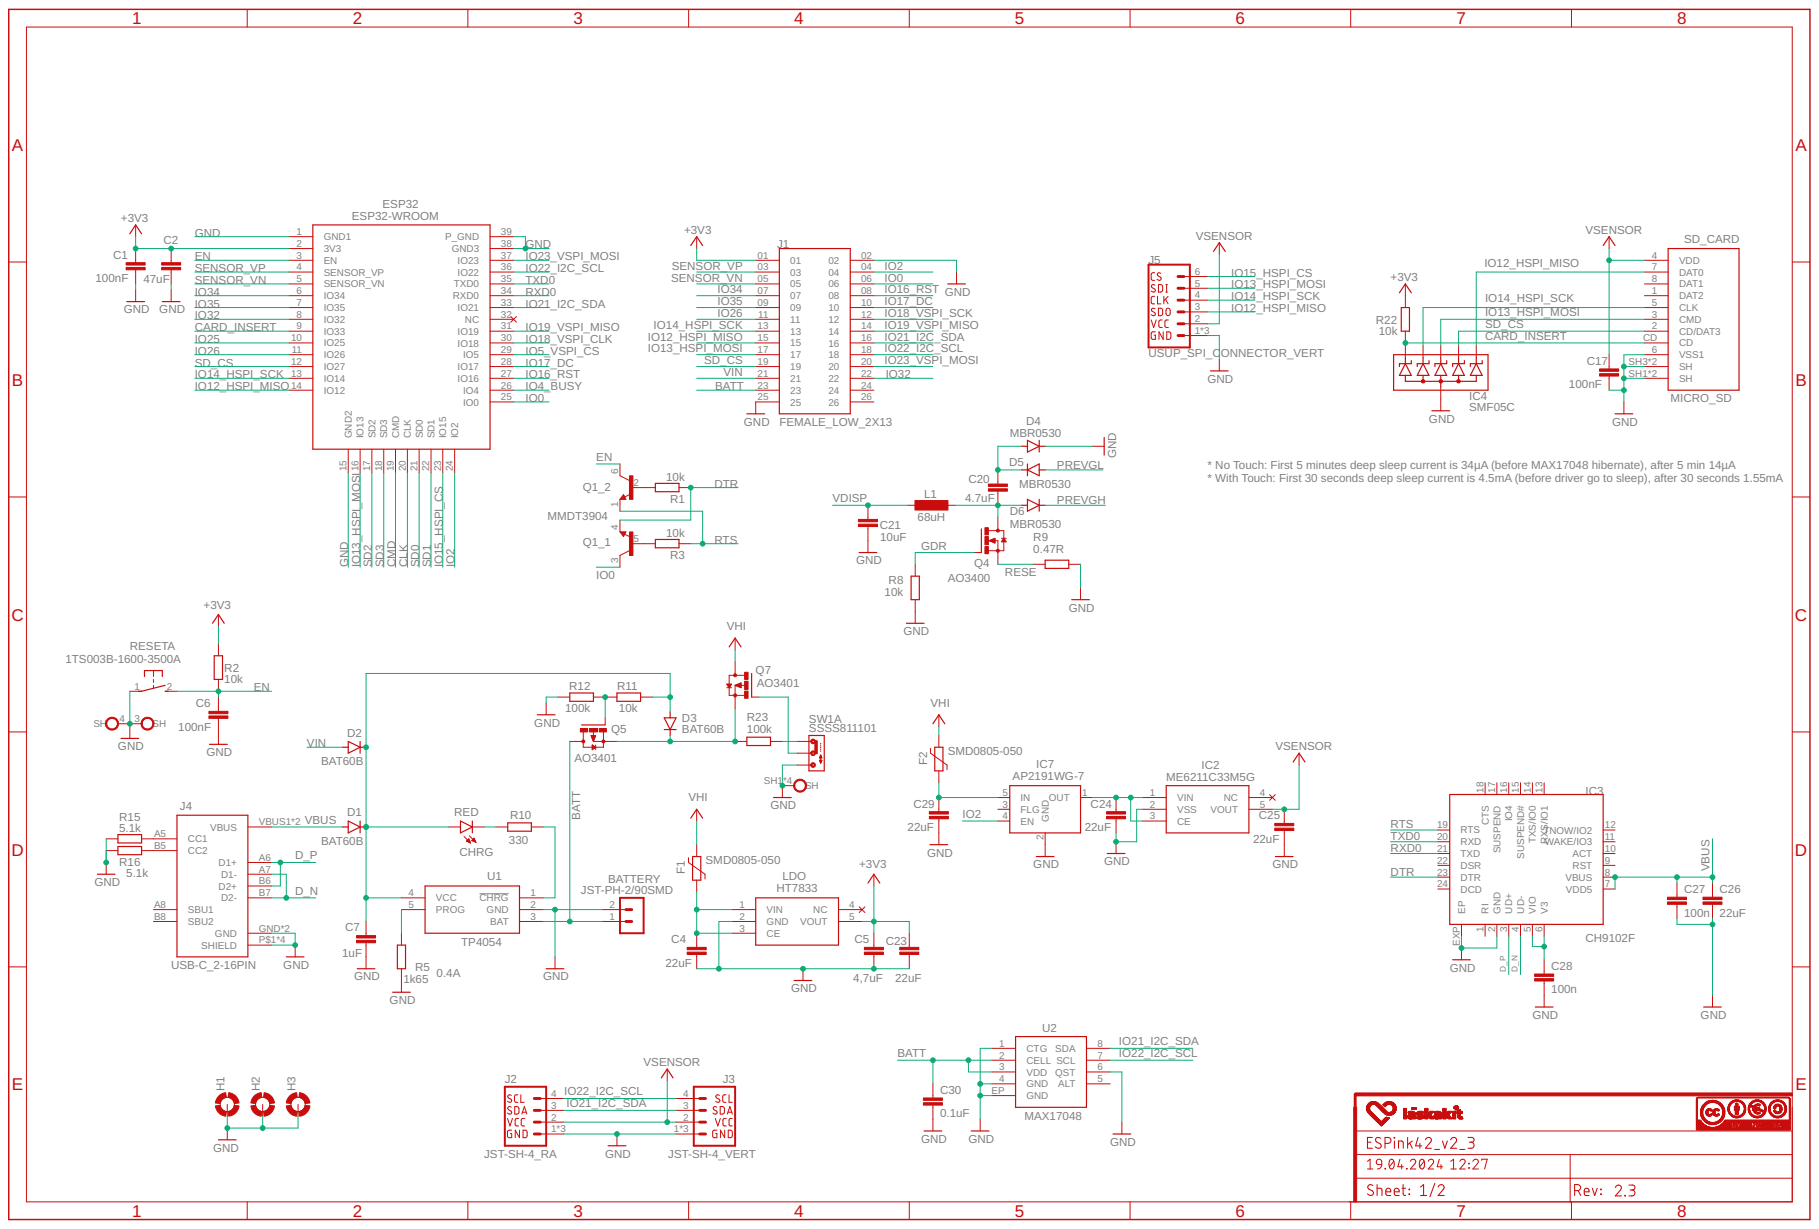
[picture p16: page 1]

* No Touch: First 5 minutes deep sleep current is 34µA (before MAX17048 hibernate), after 5 min 14µA
* With Touch: First 30 seconds deep sleep current is 4.5mA (before driver go to sleep), after 30 seconds 1.55mA

IO21_I2C_SDA 3 | 3

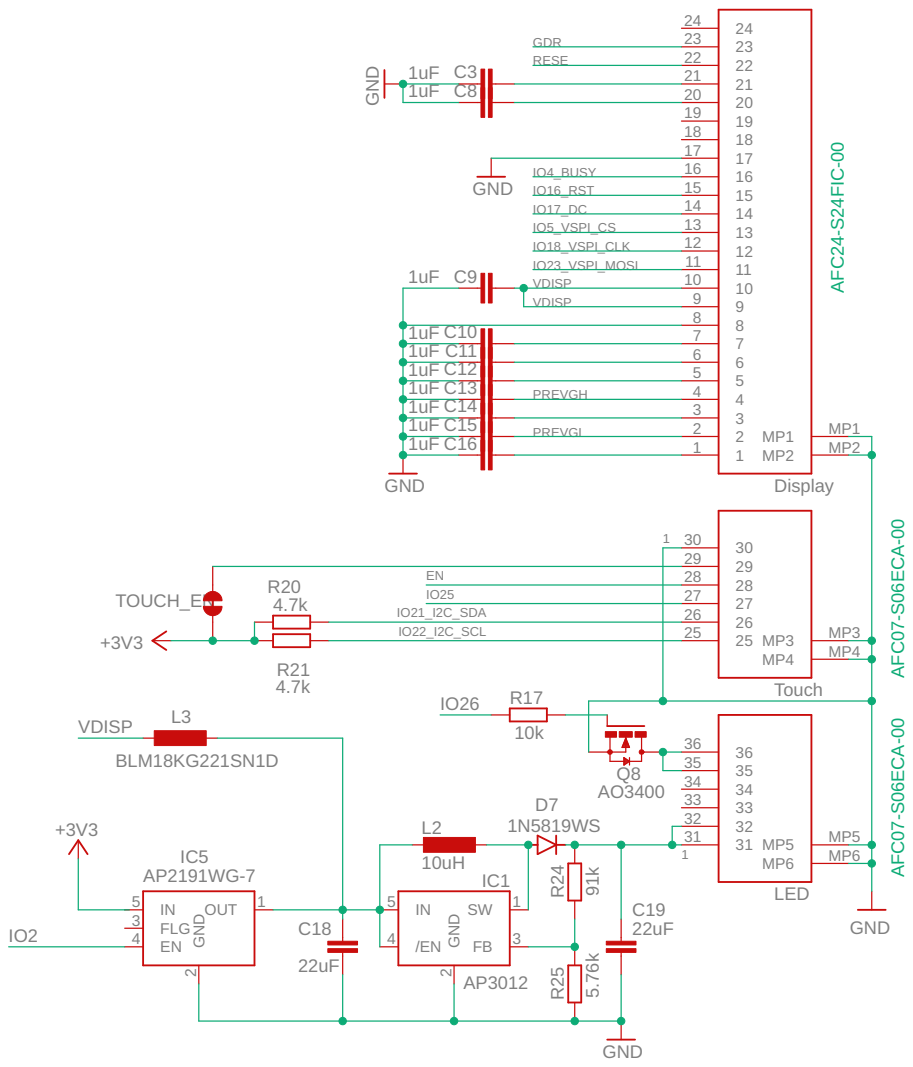
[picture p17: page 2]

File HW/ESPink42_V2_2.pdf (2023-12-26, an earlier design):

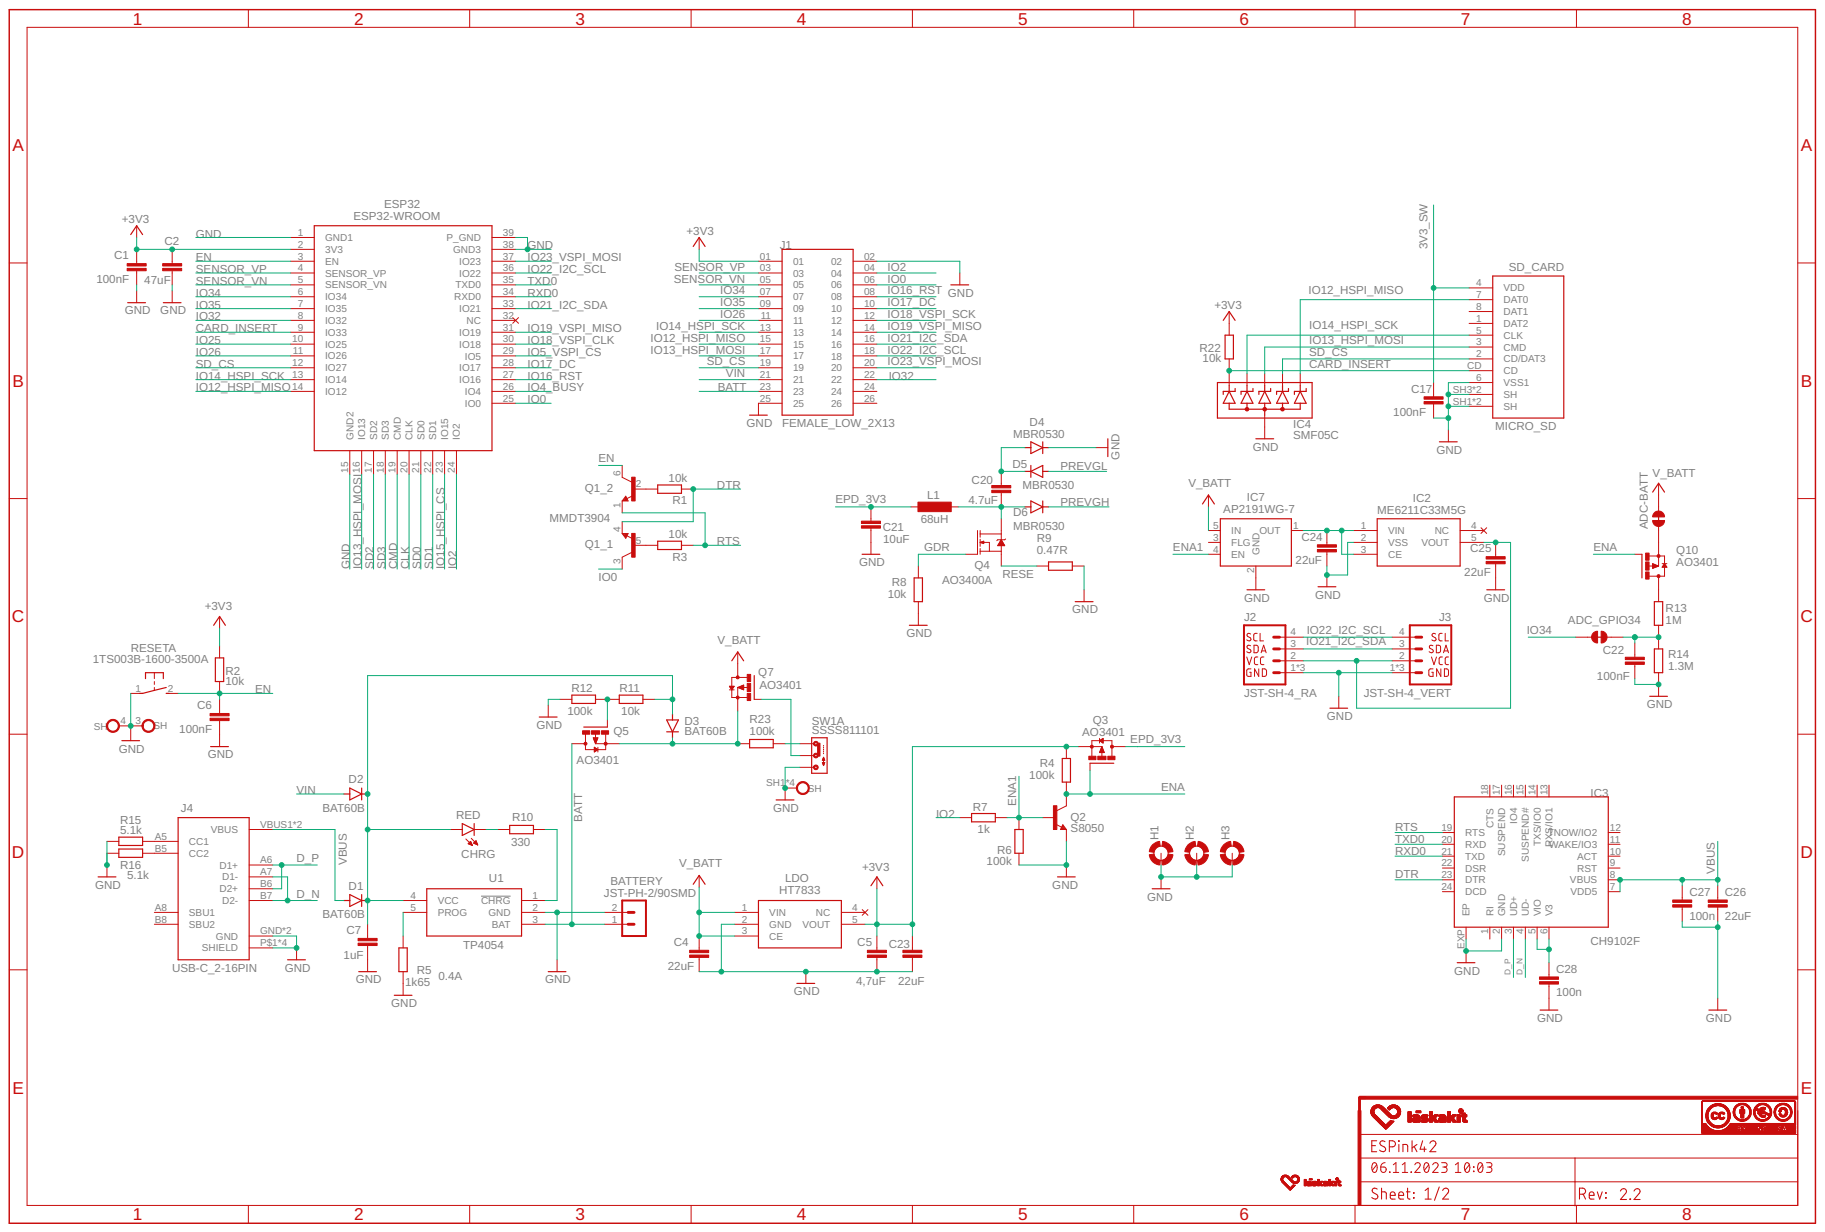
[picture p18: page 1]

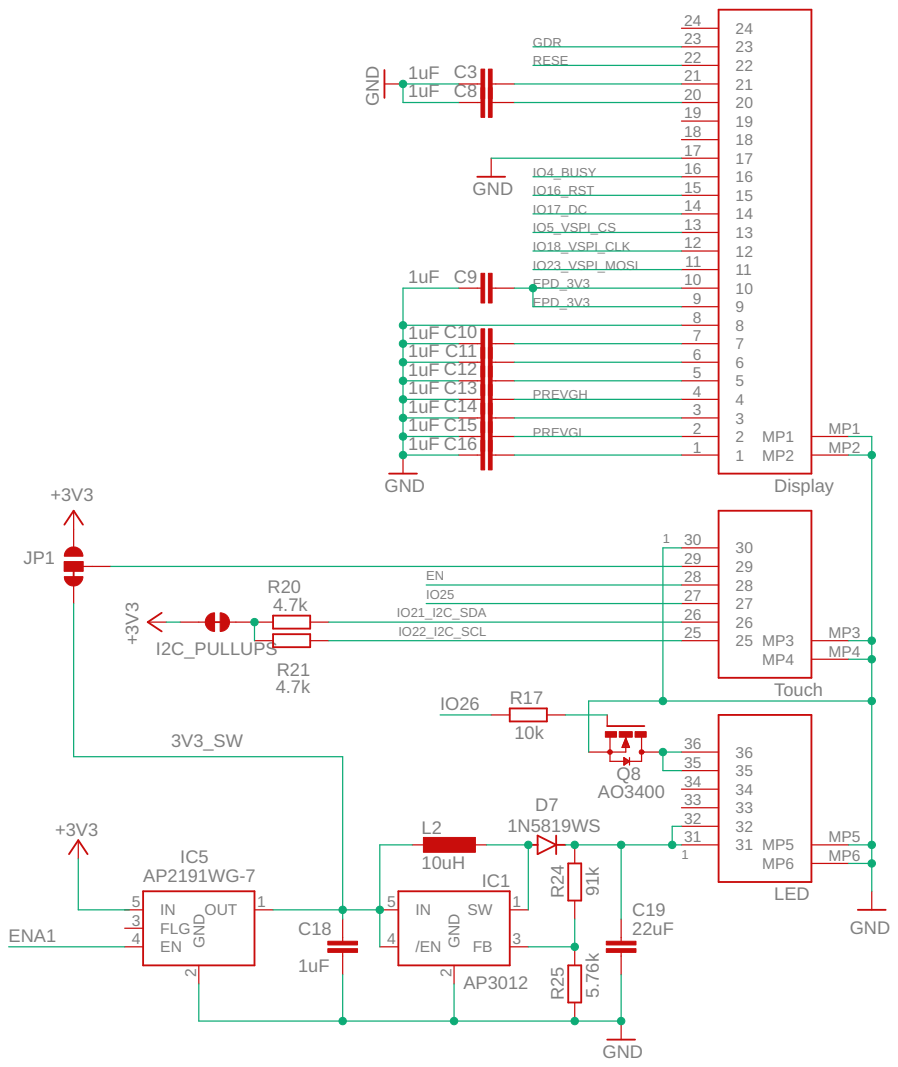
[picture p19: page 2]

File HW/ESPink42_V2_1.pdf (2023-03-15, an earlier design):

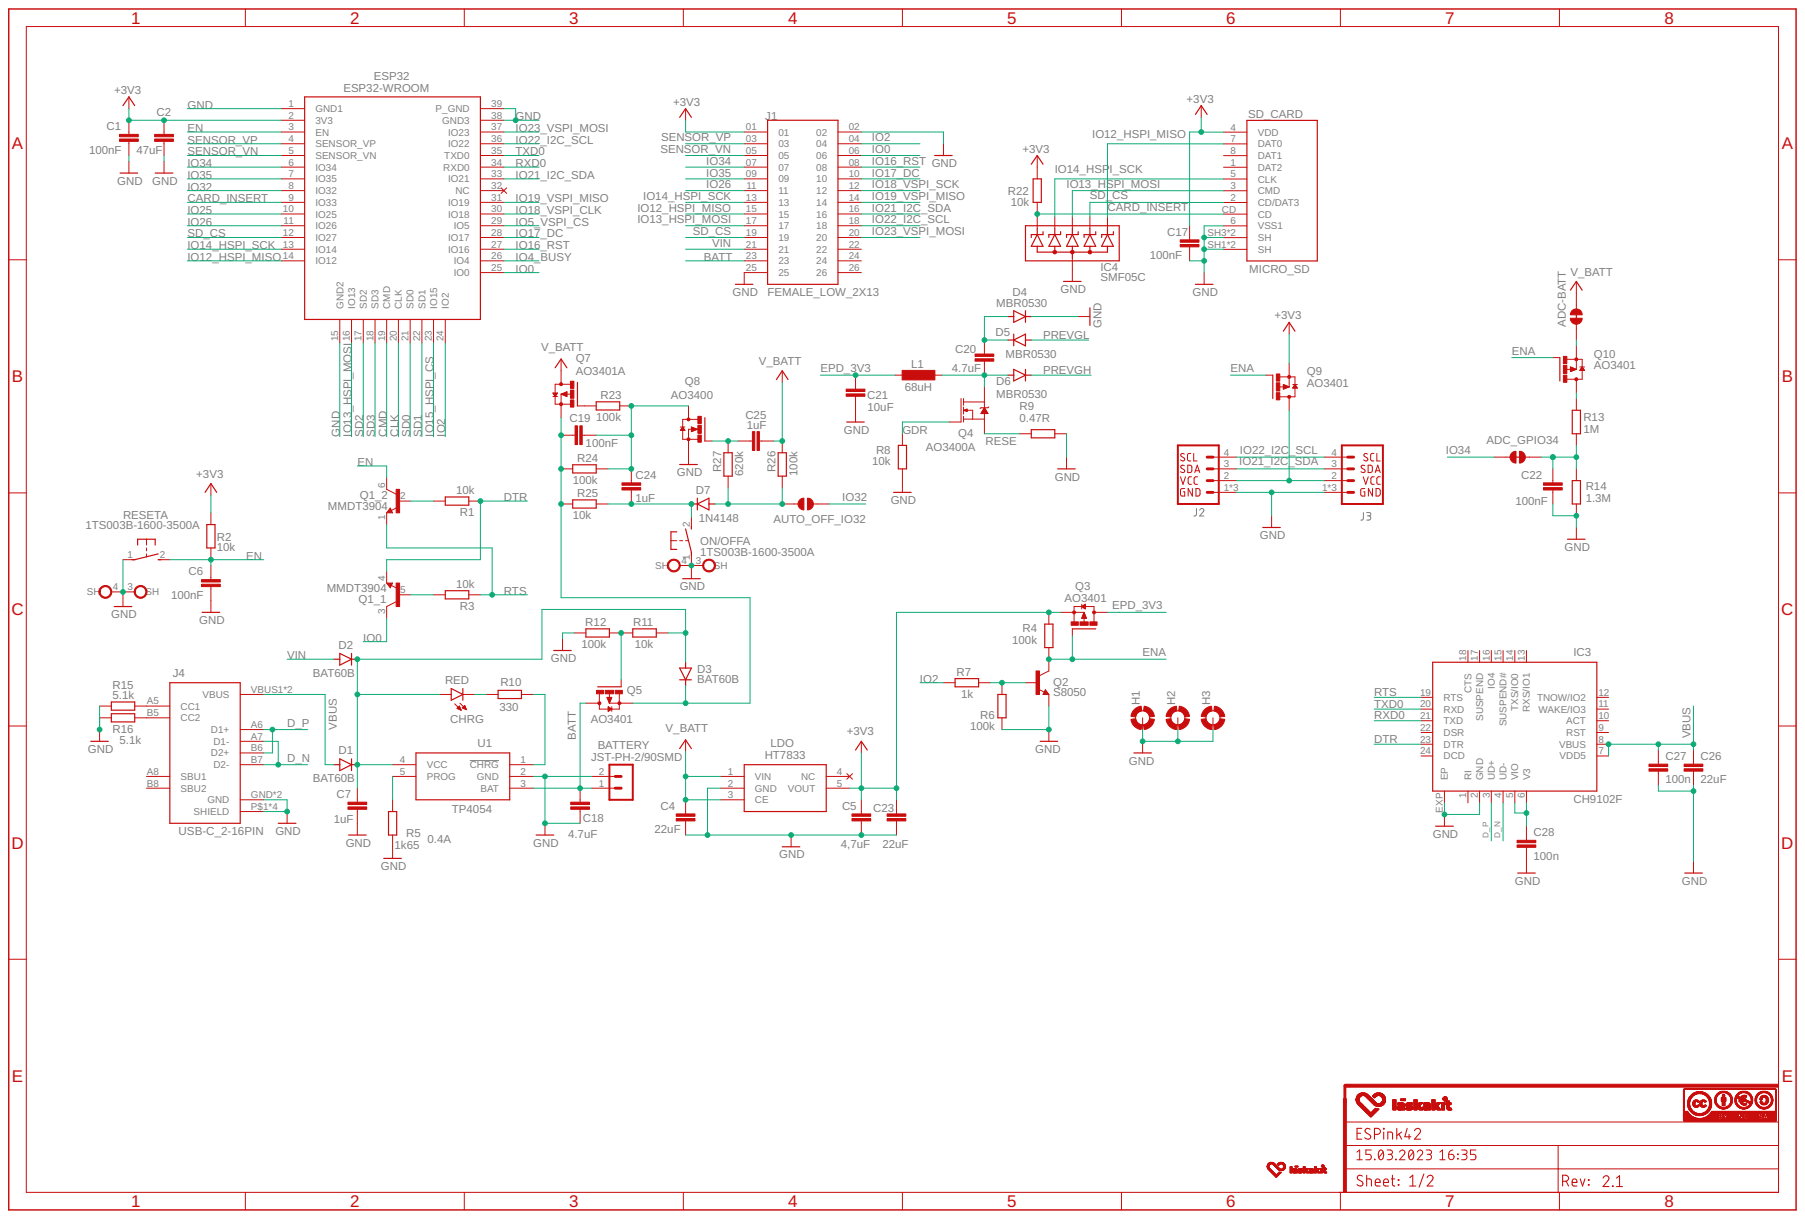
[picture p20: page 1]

3 IO21_I2C_SDA | 3

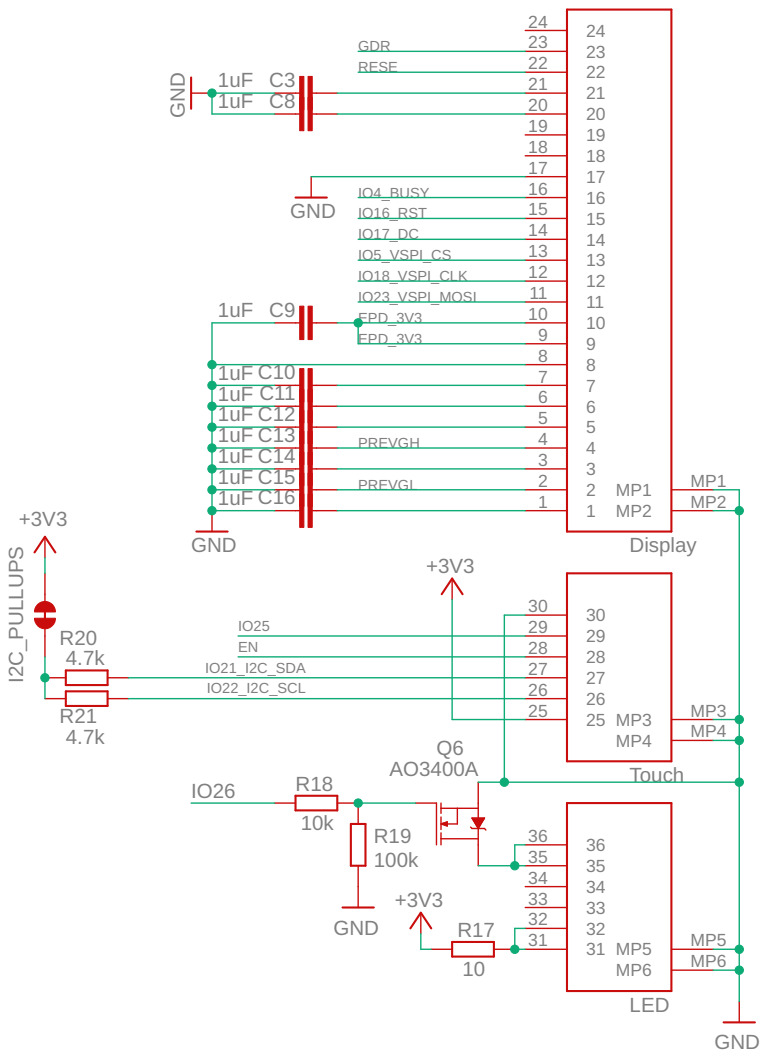
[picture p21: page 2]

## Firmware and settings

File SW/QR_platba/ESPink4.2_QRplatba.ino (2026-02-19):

/*
* Platba QR kodem primo na ucet
*
* ESPink4.2 vytvori AP (Access Point), pokud se mu do 20s nepodari pripojit k vasi Wi-Fi.
* Pokud ESPink4.2 vytvori Acess Point, prihlaste se na vytvorenou Wi-Fi "Laskakit-Platba_QR" a zadejte heslo "esp32qrpay".
* Ve webovem prohlizeci prejdete na IP zobrazenou na ePaper (nejcasteji 192.168.4.1), kde muzete zadat udaje vasi Wi-Fi.
* Ve webovem prohlizeci muze uzivatel prejit na stranku s nastavenim Wi-Fi a pripojit se do sve site.
* ESPink v obou pripadech (at uz vytvoril Access Point nebo se pripojil na Wi-Fi):
* - vytvori web stranku, kde vyplnite castku, variabilni cislo, cislo uctu a datum splatnosti.
* - QR kod se zadanymi udaji se zobrazi na ePaper displeji a zakaznik muze kod naskenovat 
* ve svem internetovem bankovnictvi a zaplatit.
* - udaje jsou zobrazeny i na ePaper displeji.
* ESPink4.2 si pamatuje prihlasovaci udaje k Wi-Fi a cislo uctu. V pripade zmeny je ulozi do pameti a priste pouzije aktualizovane.
*
* HW: ESPink4.2 https://www.laskakit.cz/laskakit-espink-42-esp32-e-paper-pcb-antenna/?variantId=13538
*
* Kompilace: Tools -> Boards -> ESP32 Dev Module
*
* Knihovny:
* https://github.com/ricmoo/qrcode/
* https://github.com/ZinggJM/GxEPD2
* https://github.com/ESP32Async/ESPAsyncWebServer
*
* laskakit (c) 2025
*
*/

#include <WiFi.h>
#include <ESPAsyncWebServer.h>
#include <EEPROM.h>
#include <GxEPD2_BW.h>
#include "qrcode_gen.h"
#include <Fonts/FreeMonoBold9pt7b.h>

#define DISPLAY_POWER_PIN 2
#define PIN_SS    5
#define PIN_DC    17
#define PIN_RST   16
#define PIN_BUSY  4

GxEPD2_BW<GxEPD2_420, GxEPD2_420::HEIGHT> display(GxEPD2_420(PIN_SS, PIN_DC, PIN_RST, PIN_BUSY));

#define EEPROM_SIZE 104
#define IBAN_ADDR      0
#define WIFI_SSID_ADDR 40
#define WIFI_PASS_ADDR 72
#define WIFI_CRED_SIZE 32
#define IBAN_SIZE      24

#define QR_SIZE 3
#define QR_PIXEL_SIZE 8

AsyncWebServer server(80);
const char* softAP_ssid = "Laskakit-Platba_QR";
const char* softAP_pass = "esp32qrpay";

// Odstraní z textu vše kromě alfanumerických znaků
String cleanIBAN(String iban) {
  String cleaned = "";
  for (unsigned int i = 0; i < iban.length(); i++) {
    char c = iban.charAt(i);
    if (isalnum(c)) {
      cleaned += c;
    }
  }
  return cleaned;
}

// Validuje základní formát českého IBAN (musí začínat CZ a mít délku 24 znaků)
bool isValidCzIBAN(String iban) {
  return (iban.startsWith("CZ") && iban.length() == 24);
}

// Převod IBAN na české číslo účtu (předčíslí - číslo účtu / kód banky)
String ibanToCzAccount(String iban) {
  if (!isValidCzIBAN(iban)) return "";
  String kodBanky = iban.substring(4, 8);
  String predcisli = iban.substring(8, 14);
  String cisloUctu = iban.substring(14, 24);

  while (predcisli.length() > 1 && predcisli.startsWith("0")) predcisli.remove(0,1);
  while (cisloUctu.length() > 1 && cisloUctu.startsWith("0")) cisloUctu.remove(0,1);

  if (predcisli.length() > 0 && predcisli != "0")
    return predcisli + "-" + cisloUctu + "/" + kodBanky;
  else
    return cisloUctu + "/" + kodBanky;
}

// EEPROM čtení/zápis účtu a WiFi stejný jako dříve
void saveAccountToEEPROM(String account) {
  for (uint8_t i = 0; i < IBAN_SIZE; i++)
    EEPROM.write(IBAN_ADDR + i, i < account.length() ? account[i] : 0);
  EEPROM.commit();
}

String loadAccountFromEEPROM() {
  char buf[IBAN_SIZE + 1];
  for (uint8_t i = 0; i < IBAN_SIZE; i++) {
    buf[i] = EEPROM.read(IBAN_ADDR + i);
    if (buf[i] < 32 || buf[i] > 126) buf[i] = ' ';
  }
  buf[IBAN_SIZE] = '\0';
  String s(buf); s.trim();
  if (!isValidCzIBAN(s)) return "";
  return s;
}

void saveWifiToEEPROM(String ssid, String pass) {
  for (uint8_t i = 0; i < WIFI_CRED_SIZE; ++i) {
    EEPROM.write(WIFI_SSID_ADDR + i, i < ssid.length() ? ssid[i] : 0);
    EEPROM.write(WIFI_PASS_ADDR + i, i < pass.length() ? pass[i] : 0);
  }
  EEPROM.commit();
}

String loadWifiSSIDFromEEPROM() {
  char buf[WIFI_CRED_SIZE + 1]; buf[WIFI_CRED_SIZE] = 0;
  for (uint8_t i = 0; i < WIFI_CRED_SIZE; ++i) buf[i] = EEPROM.read(WIFI_SSID_ADDR + i);
  String s(buf); s.trim(); return s;
}

String loadWifiPassFromEEPROM() {
  char buf[WIFI_CRED_SIZE + 1]; buf[WIFI_CRED_SIZE] = 0;
  for (uint8_t i = 0; i < WIFI_CRED_SIZE; ++i) buf[i] = EEPROM.read(WIFI_PASS_ADDR + i);
  String s(buf); s.trim(); return s;
}

String cleanSSIDorPass(String s) {
  s.trim();
  if (s.length() == 0) return "";
  for (uint8_t i = 0; i < s.length(); i++) {
    char c = s.charAt(i);
    if (c < 33 || c > 126) return "";
  }
  return s;
}

// Webový formulář
String generateHtmlForm(String currIban) {
  String html = R"rawliteral(
<!DOCTYPE HTML><html lang="cs"><head>
<meta charset="UTF-8">
<meta name="viewport" content="width=device-width, initial-scale=1, maximum-scale=1">
<title>QR Platba – ESP32</title>
<style>
body{background:#f7fafc;font-family:'Segoe UI',Tahoma,Geneva,Verdana,sans-serif;color:#222;margin:0;padding:0;display:flex;justify-content:center;align-items:center;min-height:100vh;box-sizing:border-box;}
.container{background:#fff;padding:2em 2.5em 1.5em 2.5em;border-radius:16px;box-shadow:0 6px 24px rgba(0,0,0,0.12);max-width:400px;width:95%;}
h2{font-size:1.9em;margin-bottom:1em;color:#2a4365;text-align:center;}
form{display:flex;flex-direction:column;gap:1.1em;}
label{font-weight:600;display:flex;flex-direction:column;font-size:1em;color:#2c3e50;}
input[type='number'],input[type='text'],input[type='date']{margin-top:0.4em;padding:0.6em 0.8em;border-radius:9px;border:1.5px solid #a0aec0;font-size:1.1em;background:#f7fafc;transition:border-color 0.3s ease;box-sizing:border-box;width:100%;font-family:inherit;}
input[type='number']:focus,input[type='text']:focus,input[type='date']:focus{border-color:#4299e1;outline:none;background:#fff;}
input[type='submit']{margin-top:1.2em;padding:0.75em 0;border:none;border-radius:10px;background:#4299e1;color:#fff;font-size:1.25em;font-weight:700;cursor:pointer;transition:background 0.25s ease;}
input[type='submit']:hover{background:#2b6cb0;}
.footer-link{text-align:center;margin-top:1.2em;font-size:0.95em;}
.footer-link a{color:#197dcc;text-decoration:none;}
.footer-link a:hover{text-decoration:underline;}
@media(max-width:480px){.container{padding:1.8em 1.5em 1.2em 1.5em;border-radius:0;box-shadow:none;width:100%;height:100vh;justify-content:center;}body{min-height:100vh;padding:10px;}input[type='number'],input[type='text'],input[type='date'],input[type='submit']{font-size:1.05em;}}
</style>
</head><body>
<div class="container" role="main">
<h2>Zadej údaje pro QR platbu</h2>
<form action="/qr" method="get" autocomplete="off" novalidate>
<label for="amount">Částka (Kč):
<input type="number" id="amount" name="amount" step="0.01" required placeholder="Např. 350.00" aria-required="true" />
</label>
<label for="account">IBAN:
<input type="text" id="account" name="account" pattern="CZ[0-9A-Z]{22}" maxlength="34" required value=")rawliteral" + currIban + R"rawliteral(" placeholder="CZxxxxxxxxxxxxxxxxxxxxxx" aria-required="true" />
</label>
<label for="vs">Variabilní symbol:
<input type="text" id="vs" name="vs" pattern="[0-9]{1,10}" maxlength="10" placeholder="max 10 cifer" />
</label>
<label for="date">Datum splatnosti:
<input type="date" id="date" name="date" />
</label>
<input type="submit" value="Vytvořit QR" />
</form>
<div class="footer-link" role="contentinfo"><a href="/admin">Nastavení WiFi</a></div>
</div>
</body></html>
)rawliteral";
  return html;
}

// Generování admin stránky
String generateAdminForm(String ssid, String pass) {
  ssid = cleanSSIDorPass(ssid);
  pass = cleanSSIDorPass(pass);
  String html = R"rawliteral(
<!DOCTYPE HTML><html lang="cs"><head>
<meta charset="UTF-8">
<meta name="viewport" content="width=device-width,initial-scale=1">
<title>Nastavení WiFi</title>
<style>
body{font-family:'Segoe UI',Tahoma,Geneva,Verdana,sans-serif;background:#fafaff;color:#222;display:flex;align-items:center;justify-content:center;height:100vh;margin:0;padding:0;}
.formbox{background:#fff;padding:2em 2.5em 2em 2.5em;border-radius:16px;box-shadow:0 6px 24px rgba(0,0,0,0.12);max-width:360px;width:95%;}
h2{text-align:center;margin-bottom:1em;color:#2a4365;font-size:1.8em;}
input[type='text'],input[type='password']{width:100%;font-size:1.1em;padding:0.6em 0.8em;margin-bottom:1.2em;border-radius:9px;border:1.5px solid #bbc;box-sizing:border-box;font-family:inherit;transition:border-color 0.3s ease;}
input[type='text']:focus,input[type='password']:focus{outline:none;border-color:#4299e1;background:#fff;}
input[type='submit']{width:100%;padding:0.75em 0;border:none;border-radius:10px;background:#4299e1;color:#fff;font-size:1.2em;font-weight:700;cursor:pointer;transition:background 0.25s ease;}
input[type='submit']:hover{background:#2b6cb0;}
.footer-link{text-align:center;margin-top:1em;font-size:0.95em;}
.footer-link a{color:#197dcc;text-decoration:none;}
.footer-link a:hover{text-decoration:underline;}
@media(max-width:480px){.formbox{border-radius:0;box-shadow:none;height:100vh;padding:1.8em 1.5em 1.2em 1.5em;}body{padding:10px;}}
</style>
</head><body><div class="formbox" role="main"><h2>Nastavení WiFi</h2>
<form action="/wifi_save" method="post" autocomplete="off" novalidate>
SSID:<br>
<input name="ssid" type="text" maxlength="31" value=")rawliteral" + ssid + R"rawliteral(" placeholder="SSID (název sítě)" autocomplete="off"><br>
Heslo:<br>
<input name="pass" type="password" maxlength="31" value=")rawliteral" + pass + R"rawliteral(" placeholder="Heslo sítě" autocomplete="off"><br>
<input type="submit" value="Uložit & restart">
</form>
<div class="footer-link" role="contentinfo"><a href="/">Zpět na platbu</a></div></div></body></html>
)rawliteral";
  return html;
}

String generateQRPlatba(String iban, String amount, String date, String vs) {
  date.replace("-", "");
  String qr = "SPD*1.0*ACC:" + iban + "*AM:" + amount + "*CC:CZK";
  if (date.length() == 0) qr += "*PT:IP";
  else qr += "*DT:" + date;
  if (vs.length() > 0) qr += "*X-VS:" + vs;
  Serial.print("Generuji QR řetězec: "); Serial.println(qr);
  return qr;
}

void showQRCode(const String &qrtext, const String &amount, const String &vs, const String &iban) {
  display.fillScreen(GxEPD_WHITE);
  QRCode qrcode;
  uint8_t qrcodeData[qrcode_getBufferSize(QR_SIZE)];
  qrcode_initText(&qrcode, qrcodeData, QR_SIZE, 0, qrtext.c_str());
  int qrw = QR_PIXEL_SIZE * qrcode.size;
  int offset_x = (display.width() - qrw) / 2;
  int offset_y = 16;
  for (int y = 0; y < qrcode.size; y++) {
    for (int x = 0; x < qrcode.size; x++) {
      if (qrcode_getModule(&qrcode, x, y)) {
        display.fillRect(offset_x + x * QR_PIXEL_SIZE, offset_y + y * QR_PIXEL_SIZE, QR_PIXEL_SIZE, QR_PIXEL_SIZE, GxEPD_BLACK);
      }
    }
  }
  int txt_y = offset_y + qrw + 8 + 10;
  display.setTextColor(GxEPD_BLACK);
  display.setFont(&FreeMonoBold9pt7b);
  display.setCursor(18, txt_y);
  display.print("Castka: ");
  display.print(amount);
  display.print(" Kc");
  txt_y += 32;
  display.setCursor(18, txt_y);
  display.print("Ucet: ");
  txt_y += 28;

  String domaciUcet = ibanToCzAccount(iban);
  display.setCursor(18, txt_y);
  display.println(domaciUcet.length() > 0 ? domaciUcet : iban);
  if (vs.length() > 0) {
    txt_y += 32;
    display.setCursor(18, txt_y);
    display.print("VS: ");
    display.println(vs);
  }
  display.setFont(NULL);
  display.display(true);
}

void showWifiInfo(const char* status, const char* ssid, IPAddress ip) {
  display.fillScreen(GxEPD_WHITE);
  display.setTextSize(2);
  display.setCursor(8, 24);
  display.print("WiFi: ");
  display.println(status);
  display.setTextSize(1);
  int y = 56;
  if (ssid && strlen(ssid) > 0) {
    display.setCursor(8, y);
    display.print("SSID: ");
    display.println(ssid);
    y += 24;
  }
  display.setCursor(8, y);
  display.print("IP: ");
  display.println(ip);
  display.display(true);
}

void setup() {
  Serial.begin(115200);
  Serial.println("--- Spouštím ESP32 QR server ---");

  pinMode(DISPLAY_POWER_PIN, OUTPUT);
  digitalWrite(DISPLAY_POWER_PIN, HIGH);
  delay(500);

  display.init();
  display.setRotation(1);
  display.setTextColor(GxEPD_BLACK);

  EEPROM.begin(EEPROM_SIZE);

  String wifi_ssid = loadWifiSSIDFromEEPROM();
  String wifi_pass = loadWifiPassFromEEPROM();
  if (wifi_ssid.length() < 2) {
    wifi_ssid = "TVAJE_VYCHOZI_SIT";
    wifi_pass = "TVOJE_HESLO";
  }

  bool wifi_connected = false;
  Serial.print("Připojuji k WiFi: ");
  Serial.println(wifi_ssid);

  WiFi.mode(WIFI_STA);
  WiFi.begin(wifi_ssid.c_str(), wifi_pass.c_str());

  unsigned long startAttemptTime = millis();
  while (!wifi_connected && millis() - startAttemptTime < 20000) {
    if (WiFi.status() == WL_CONNECTED) {
      wifi_connected = true;
      break;
    }
    delay(250);
    Serial.print(".");
  }
  Serial.println();

  if (wifi_connected) {
    Serial.print("Připojeno na WiFi: ");
    Serial.println(WiFi.SSID());
    Serial.print("IP adresa: ");
    Serial.println(WiFi.localIP());
    showWifiInfo("Pripojeno", WiFi.SSID().c_str(), WiFi.localIP());
  } else {
    WiFi.disconnect(true);
    Serial.println("WiFi se nepodařilo připojit, spouštím Access Point...");
    WiFi.mode(WIFI_AP);
    WiFi.softAP(softAP_ssid, softAP_pass);
    IPAddress apIP = WiFi.softAPIP();
    Serial.print("AP SSID: ");
    Serial.println(softAP_ssid);
    Serial.print("AP IP : ");
    Serial.println(apIP);
    showWifiInfo("AP REZIM", softAP_ssid, apIP);
  }

  server.on("/", HTTP_GET, [](AsyncWebServerRequest *request) {
    Serial.println("HTTP GET /");
    String savedIban = loadAccountFromEEPROM();
    request->send(200, "text/html; charset=utf-8", generateHtmlForm(savedIban));
  });

  server.on("/qr", HTTP_GET, [](AsyncWebServerRequest *request) {
    Serial.println("HTTP GET /qr");

    String ibanRaw = request->getParam("account")->value();
    String iban = cleanIBAN(ibanRaw);

    String amount = request->getParam("amount")->value();
    String vs = "";
    if (request->hasParam("vs"))
      vs = request->getParam("vs")->value();
    String date = request->getParam("date")->value();

    if (!isValidCzIBAN(iban)) {
      request->send(200, "text/html; charset=utf-8",
        "<!DOCTYPE html><html lang='cs'><head><meta charset='UTF-8'/><meta name='viewport' content='width=device-width, initial-scale=1'/>"
        "<title>Chyba - QR platba</title><style>body{font-family:sans-serif;padding:20px;}</style></head><body>"
        "<h3>Chyba: Číslo účtu musí být český IBAN bez mezer a o délce 24 znaků!</h3><p><a href='/'>Zpět</a></p></body></html>");
      Serial.println("Chyba: neplatný IBAN!");
      return;
    }

    if (amount.toFloat() <= 0.0) {
      request->send(200, "text/html; charset=utf-8",
        "<!DOCTYPE html><html lang='cs'><head><meta charset='UTF-8'/><meta name='viewport' content='width=device-width, initial-scale=1'/>"
        "<title>Chyba - QR platba</title><style>body{font-family:sans-serif;padding:20px;}</style></head><body>"
        "<h3>Chyba: Částka musí být větší než 0!</h3><p><a href='/'>Zpět</a></p></body></html>");
      Serial.println("Chyba: částka <= 0.");
      return;
    }

    if (vs.length() > 0 && (vs.length() > 10 || vs.toInt() <= 0)) {
      request->send(200, "text/html; charset=utf-8",
        "<!DOCTYPE html><html lang='cs'><head><meta charset='UTF-8'/><meta name='viewport' content='width=device-width, initial-scale=1'/>"
        "<title>Chyba - QR platba</title><style>body{font-family:sans-serif;padding:20px;}</style></head><body>"
        "<h3>Chyba: Variabilní symbol musí být číslo do 10 cifer.</h3><p><a href='/'>Zpět</a></p></body></html>");
      Serial.println("Chyba: špatný VS.");
      return;
    }

    String savedIban = loadAccountFromEEPROM();
    if (iban != savedIban) {
      saveAccountToEEPROM(iban);
      Serial.println("Nový IBAN uložen do EEPROM.");
    }

    String platbaQR = generateQRPlatba(iban, amount, date, vs);
    showQRCode(platbaQR, amount, vs, iban);

    String msg = "<!DOCTYPE html><html lang='cs'><head><meta charset='UTF-8'/><meta name='viewport' content='width=device-width, initial-scale=1'/>"
      "<title>QR platba</title><style>body{font-family:'Segoe UI', Tahoma, Geneva, Verdana, sans-serif; padding:2em; background:#f7fafc; color:#222;}"
      ".message{max-width:320px; margin:3em auto; padding:1.8em 2em; background:#fff; box-shadow:0 4px 18px rgba(0,0,0,0.1); border-radius:12px; text-align:center; font-size:1.15em; line-height:1.4;}"
      "a{display:inline-block; margin-top:1.25em; color:#197dcc; text-decoration:none; font-weight:600;} a:hover{text-decoration:underline;}</style></head><body>"
      "<div class='message'><b>QR kód je zobrazen na displeji!</b><br><a href='/'>Zpět</a></div></body></html>";
    request->send(200, "text/html; charset=utf-8", msg);
    Serial.println("QR kód úspěšně zobrazen na displeji.");
  });

  server.on("/admin", HTTP_GET, [](AsyncWebServerRequest* request) {
    String currSSID = loadWifiSSIDFromEEPROM();
    String currPass = loadWifiPassFromEEPROM();
    String page = generateAdminForm(currSSID, currPass);
    request->send(200, "text/html; charset=utf-8", page);
  });

  server.on("/wifi_save", HTTP_POST, [](AsyncWebServerRequest* request) {
    String ssid = request->getParam("ssid", true)->value();
    String pass = request->getParam("pass", true)->value();
    saveWifiToEEPROM(ssid, pass);
    Serial.println("[WiFi] Uživatelské nastavení ulozeno do EEPROM");
    request->send(200, "text/html; charset=utf-8",
      "<!DOCTYPE html><html lang='cs'><head><meta charset='UTF-8'/><meta name='viewport' content='width=device-width, initial-scale=1' />"
      "<title>WiFi Uloženo</title><style>body{font-family:sans-serif;padding:20px;background:#f7fafc;color:#222;text-align:center;}"
      "a{color:#197dcc;text-decoration:none;font-weight:600;} a:hover{text-decoration:underline;}.msgbox{max-width:320px;margin:3em auto;padding:1.8em 1em;background:#fff;box-shadow:0 4px 18px rgba(0,0,0,0.1);border-radius:12px;}"
      "</style></head><body><div class='msgbox'><b>Uloženo! Nové údaje se použijí po restartu zařízení.</b><br><br><a href='/admin'>Zpět na nastavení WiFi</a></div></body></html>");
    delay(1200);
    ESP.restart();
  });

  server.begin();
  Serial.println("Webserver spuštěn.");
}

void loop() {
  // program běží asynchronně přes server
}

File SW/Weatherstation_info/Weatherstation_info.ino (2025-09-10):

/*
* Example code shows values from weatherstation from TMEP.cz (temperature, humidity, pressure, battery voltage) 
* and BME280 (temperature/humidity), battery voltage on eInk/ePaper display
*
* Compile as ESP32 dev module
* ESPink - ESP32 board for ePaper: https://www.laskakit.cz/laskakit-espink-esp32-e-paper-pcb-antenna/
* BME280 (https://www.laskakit.cz/arduino-senzor-tlaku--teploty-a-vlhkosti-bme280/) is connected through uSup connector 
***********************************************
* Based on your settings, you have to change:
* WiFi setting - SSID and Password
* TMEP server - jsonurl
***********************************************
* Libraries:
* EPD library: https://github.com/ZinggJM/GxEPD2
* ArduinoJson: https://arduinojson.org/
* NTPClient: https://github.com/arduino-libraries/NTPClient
* Font: https://oleddisplay.squix.ch/ 
* BME280: https://github.com/adafruit/Adafruit_BME280_Library
* https://github.com/adafruit/Adafruit_Sensor
***********************************************
* made by laskakit (c) 2023
*/
 
#include <WiFi.h>

// ePaper
#include <GxEPD2_BW.h>
#include "SPI.h"

// NTPClient
#include "time.h"
#include "sntp.h"

// ArduinoJson
#include <ArduinoJson.h>

// BME280
#include <Wire.h>
#include <Adafruit_Sensor.h>
#include <Adafruit_BME280.h>
 
// Fonts
#include "OpenSansSB_12px.h"
#include "OpenSansSB_24px.h"
#include "OpenSansSB_50px.h"

      /***********************/
      /* PLEASE, CHANGE THIS */
      /***********************/
/* -----------------WiFi network ---------------- */
char ssid[] = "xxx";
char pass[] = "xxx";
/* ---------------------------------------------- */

/* -------------------TMEP setting--------------- */
const char* host = "tmep.cz"; // TMEP.cz or TMEP.eu
const int httpPort = 80;
//You can try with our test Weather Station first 
//const char* jsonurl = "https://tmep.cz/vystup-json.php?id=4551&export_key=bx9hd5jq8g&extended=1"; //LasKKit Test Weather Station, Rychnov nad Kneznou
const char *jsonurl = "https://tmep.cz/vystup-json.php?id=6707&export_key=68t2vd093s&extended=1";  // LaskaKit Maker Faire Weather Station
/* ---------------------------------------------- */

/* ---------- Deepsleep time in seconds --------- */
#define deepSleepTime 300
/* ---------------------------------------------- */

/* -------------------Board--------------- */
//#define ESPink42_V2     //for version v2.4 and earlier
#define ESPink42_V3     //for version v3.0 and above

#ifdef ESPink42_V2
  //MOSI/SDI    23
  //CLK/SCK     18
  //SS/CS       5
  #define DC    17 
  #define RST   16  
  #define BUSY  4 
  #define POWER 2
  #define SDA   21
  #define SCL   22
  #define BAT   34
  #define DISPLAY_LED 26      // Display backlight pin
#else ESPink42_V3
  //MOSI/SDI    11
  //CLK/SCK     12
  //SS/CS       10
  #define DC    48 
  #define RST   45  
  #define BUSY  38 
  #define POWER 47
  #define SDA   42
  #define SCL   2
  #define BAT   9
  #define DISPLAY_LED 1      // Display backlight pin
#endif

// E-paper display
GxEPD2_BW<GxEPD2_420_GDEY042T81, GxEPD2_420_GDEY042T81::HEIGHT> display(GxEPD2_420_GDEY042T81(SS, DC, RST, BUSY)); //GDEY042T81 (GDEY042T81-FT02), 400x300, SSD1683 (no inking)
//GxEPD2_4C<GxEPD2_420c_GDEY0420F51, GxEPD2_420c_GDEY0420F51::HEIGHT> display(GxEPD2_420c_GDEY0420F51(SS, DC, RST, BUSY)); // GDEY0420F51 400x300, HX8717 (no inking)
//GxEPD2_3C<GxEPD2_420c_GDEY042Z98, GxEPD2_420c_GDEY042Z98::HEIGHT> display(GxEPD2_420c_GDEY042Z98(SS, DC, RST, BUSY)); // GDEY042Z98 400x300, SSD1683 (no inking)

/*  ------------------------------------------------------------------------------------------------- */

/*-------------- ePaper resolution----------------*/
#define DISPLAY_RESOLUTION_X 400
#define DISPLAY_RESOLUTION_Y 300
/* ---------------------------------------------- */

/* -------------------NTP Client----------------- */
const char* ntpServer1 = "pool.ntp.org";
const char* ntpServer2 = "time.nist.gov";
// A list of rules for your zone could be obtained from https://github.com/esp8266/Arduino/blob/master/cores/esp8266/TZ.h
const char* time_zone = "CET-1CEST,M3.5.0,M10.5.0/3"; // Prague time zone
/* ---------------------------------------------- */

/* ---- ADC reading - indoor Battery voltage ---- */
#define dividerRatio 1.7693877551  // Voltage devider ratio on ADC pin 1MOhm + 1.3MOhm
/* ---------------------------------------------- */

/* -------------------SHT40--------------------- */
#include "Adafruit_SHT4x.h"
Adafruit_SHT4x sht4 = Adafruit_SHT4x();
/* ---------------------------------------------- */

/* variables */
float temperature_out;  // temperature from outdoor weatherstation (from tmep.cz)
int pressure_out; // pressure from outdoor weatherstation (from tmep.cz)
int humidity_out; // humidity from outdoor weatherstation (from tmep.cz)
float m_volt; // battery voltage from outdoor weatherstation (from tmep.cz)

String date; // actual time

int strength; // Wi-Fi signal strength

int percentage; // indoor battery voltage in percent
float d_volt; // indoor battery voltage
float temperature_in; // indoor temperature from SHT40
int humidity_in; // indoor humidity from SHT40
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

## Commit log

2022-11-03 new data
    [ESPink42_top_bom.csv, ESPink_top_bom.csv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]
2023-02-10 new ver
    [ESPink42_top_bom.csv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]
2023-03-17 old data
    [ESPink42_top_bom_2023-02-03.csv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]
2023-03-31 Add I2C example
2023-04-02 Add ADC test and SD test
2023-04-03 Add fast update for Weatherstation and fix time
    [Weatherstation_info.ino]
2023-04-03 Convert all projects to Arduino IDE
2023-04-23 Fix I2C scan test
    [I2C_test.ino]
2023-05-25 new 3D
    [ESPink-42_v2.2_case.3mf]
2023-05-26 connector moved 0.2mm
2023-05-26 new slim case
    [ESPink-42_v2.2_case.3mf]
2023-05-27 new case
    [ESPink-42_v2-2_case.3mf, ESPink-42_v2.2_case.3mf]
2023-05-27 batt devider ration mistake fixed
    [ADC_test.ino, GxEPD2_SHT40.ino, Weatherstation_info.ino]
2024-08-11 Fix ADC reading
2024-09-02 Compatibility with arduino-esp32: 3.x
2025-05-18 fixed changes in esp v3.0
    [Touch_and_light_example.ino, complete_test.ino]
2026-02-19 stand added
    [ESPink-42_case_v3.3mf]
2026-05-22 moved to https://github.com/LaskaKit/Live
    [ESPink-42_case_v3.3mf]
2026-06-01 new ver, movedf
    [ESPink42_v2_3_top_bom.csv, ESPink42_v3_0_bom.csv, ESPink42_v3_1_JLCPCB_BOM.csv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]
